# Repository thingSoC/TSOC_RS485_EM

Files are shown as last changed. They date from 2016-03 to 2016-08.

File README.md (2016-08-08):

# TSOC_RS485_EM
**TSOC_RS485_EM** is a ATMEGA328 based board with integrated RS485 driver, an Embedded Module for thingSoC.

The **TSOC_RS485_EM** connects any thingSoC or Mikrobus module to an RS485 compatible slave interface,
including a variety of analog sensors, such as Temperature, Wind, Pressure, Air Quality, and much more.
The **TSOC_RS485_EM** can be configured as either a thingSoC master module (female connectors), or a thingSoC slave module (male connectors),
which is implemented as an assembly/build time option.
 
---------------------------------------

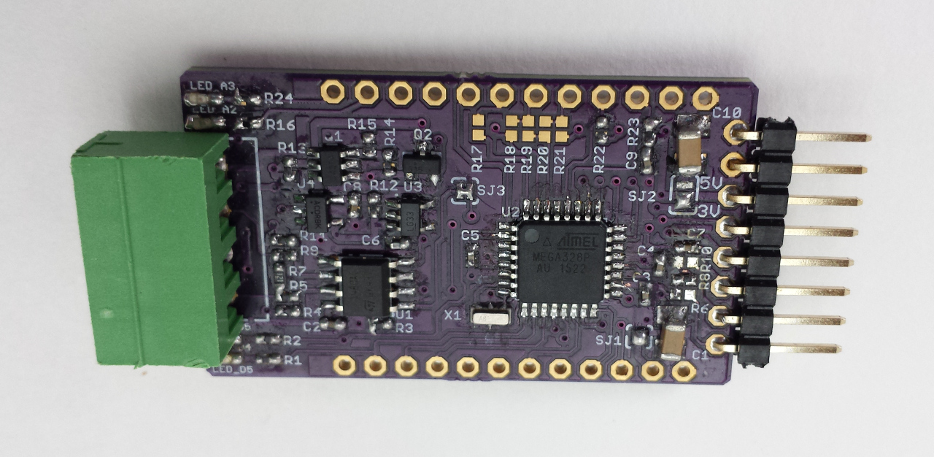
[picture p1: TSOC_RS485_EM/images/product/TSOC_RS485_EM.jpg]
thingSoC TSOC_NEOLED
[TSOC_RS485_EM](https://github.com/thingSoC/TSOC_RS485_EM/)

* [thingSoC Compliant Module](http://www.thingsoc.com)
* [Mikrobus Compatible Module](http://www.mikroe.com/mikrobus/) 
* [Modbus](http://www.modbus.org/specs.php) Compliant Slave Interface
* [5 Volt](https://en.wikipedia.org/wiki/Modbus) Nominal Power Input with ESD and OV/OC protections
* Supports Analog  Inputs  (ADC) 
* Supports Digital Outputs (GPIO)
* Supports Digital Inputs  (GPIO)
* Supports Remote I2C Interface
* Supports Remote UART Interface
* Supports Remote SPI Interface

## Protocols

* DMX512, RDM512
* Modbus
* Vending Machine Bus

---------------------------------------
## Example Applications

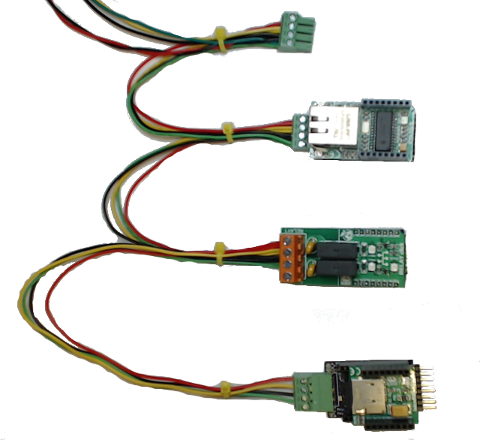
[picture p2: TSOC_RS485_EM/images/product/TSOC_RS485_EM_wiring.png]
thingSoC TSOC_NEOLED
[TSOC_RS485_EM Example Wiring](https://github.com/thingSoC/TSOC_RS485_EM/)

* [Modbus Weather Sensor](http://www.mikroe.com/click/weather/) BOSCH BME280 Temp, Humidity, Air Pressure
* [Modbus Methane Sensor](http://www.mikroe.com/click/methane/) MQ-4 Sensor for Methane (CH4) 
* [Modbus Air Quality Sensor](http://www.mikroe.com/click/air-quality/) MQ-135 Sensor for Harmful Gasses
* [Modbus Lightning Sensor](http://www.mikroe.com/click/thunder/) AS3935 Lighting Strike Detector
* [Modbus Controlled Relay](http://www.mikroe.com/click/relay/) G6D1AASI Power Relay Control Module

---------------------------------------
## 3D Model (Sketchup)

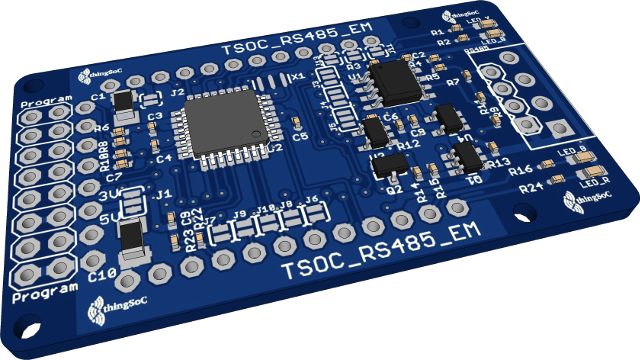
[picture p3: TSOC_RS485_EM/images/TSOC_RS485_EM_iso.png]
thingSoC TSOC_RS485_EM


---------------------------------------
## Project Status

* 02/18/2016 : Revision 4.0 Release for PCB fab
* 03/07/2016 : First Prototypes, board bringup is good
* 03/14/2016 : Revision 5.0 Released for PCB
* 04/06/2016 : Revision 6.0 Released for PCB

## Revision 6.0 Notes: ##

* Pinout Changes, D5/D8/D9 added as a second serial choice
* Disconnect jumpers added to all shared pins
* A7 used as AREF calibration input
* A6 used as VCC monitor input
* Both 3.5mm and 2.54mm connector patterns added

---------------------------------------

## Documentation Index <a name="documentation_index"/>

[TSOC_RS485_EM Quick Start Guide](https://github.com/thingSoC/TSOC_RS485_EM/blob/master/TSOC_RS485_EM/docs/QuickStart.md)

[TSOC_RS485_EM User Guide](https://github.com/thingSoC/TSOC_RS485_EM/blob/master/TSOC_RS485_EM/docs/UserGuide.md)

[TSOC_RS485_EM Theory of Operation](https://github.com/thingSoC/TSOC_RS485_EM/blob/master/TSOC_RS485_EM/docs/TheoryOfOperation.md)

[thingSoC Organization Website](http://thingSoC.github.io)

[thingSoC FAQ - Frequently Asked Questions](http://thingsoc.github.io/support/faq.html)

---------------------------------------

[  
*thingSoC*](http://thingsoc.github.io)

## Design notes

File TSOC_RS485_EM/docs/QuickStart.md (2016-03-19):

# TSOC_RS485_EM Quick Start Guide

Welcome! <br>
The **TSOC_RS485_EM**  Quick Start Guide is a series of quick steps to try out your new board.

---------------------------------------

## Quick Start Guide <a name="quickstartguide_index"/>

1. Plug a USB-UART (such as an FTDI cable) from your computer/tablet/etc. 
   or other USB power source to the **TSOC_RS485_EM**
2. Open the Arduino IDE
3. Select "Tools -> Board Manager -> Board -> Ardunio Pro or Mini"
4. Select "Tools -> Port -> COMX:", where X is your USB-UART
5. Select "File -> Examples -> Basics -> Blink"
6. Change "int LED=13;" to "int LED=5;" to blink the Yellow LED  
   Change "int LED=13;" to "int LED=4;" to blink the Blue LED  
   Change "int LED=13;" to "int LED=A2;" to blink the Green LED  
   Change "int LED=13;" to "int LED=A3;" to blink the Red LED  
7. Select "Sketch -> Upload" to load your sketch into the **TSOC_RS485_EM**
8. Observe the LED Blinking

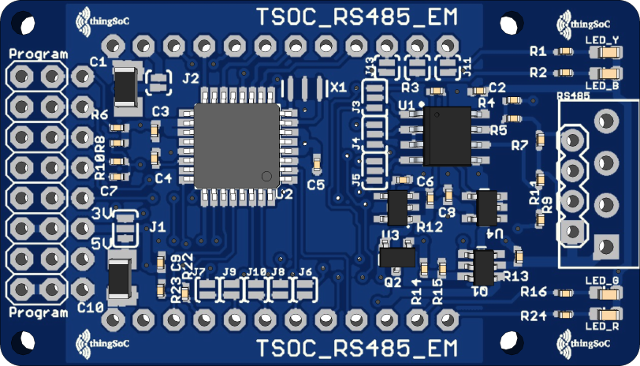
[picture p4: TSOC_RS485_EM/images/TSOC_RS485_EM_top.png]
thingSoC TSOC_RS485_EM
[  
*TSOC_RS485_EM*](https://github.com/thingSoC/TSOC_RS485_EM/)

---------------------------------------

## Documentation Index <a name="documentation_index"/>

[TSOC_RS485_EM Quick Start Guide](https://github.com/thingSoC/TSOC_RS485_EM/blob/master/TSOC_RS485_EM/docs/QuickStart.md)

[TSOC_RS485_EM User Guide](https://github.com/thingSoC/TSOC_RS485_EM/blob/master/TSOC_RS485_EM/docs/UserGuide.md)

[TSOC_RS485_EM Theory of Operation](https://github.com/thingSoC/TSOC_RS485_EM/blob/master/TSOC_RS485_EM/docs/TheoryOfOperation.md)

[thingSoC Organization Website](http://thingSoC.github.io)

[thingSoC FAQ - Frequently Asked Questions](http://thingsoc.github.io/support/faq.html)

---------------------------------------

[  
*thingSoC*](http://thingsoc.github.io)

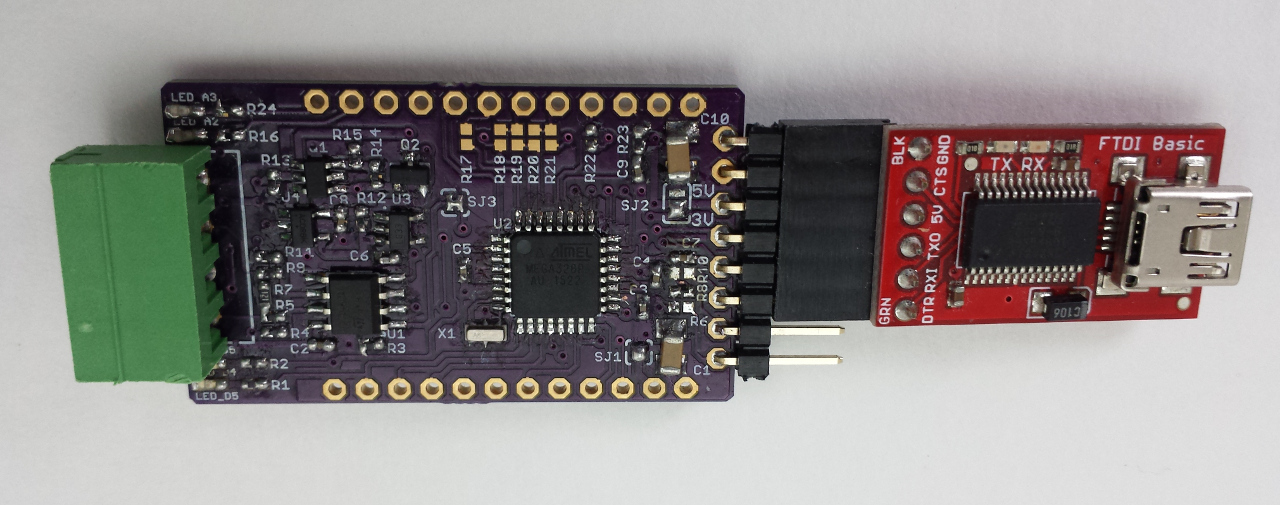
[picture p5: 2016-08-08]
TSOC_RS485_EM/images/product/TSOC_RS485_EM_prog_FTDI.jpg

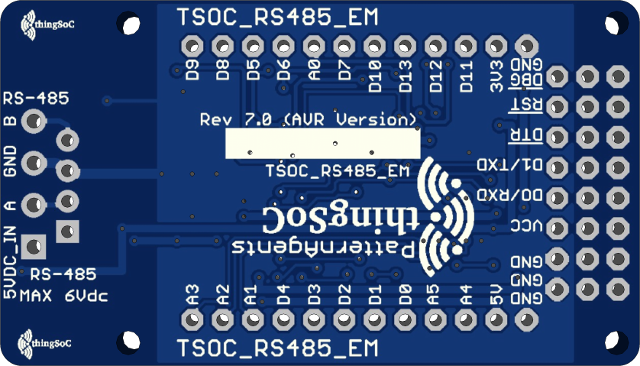
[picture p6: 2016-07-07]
TSOC_RS485_EM/images/TSOC_RS485_EM_bot.png

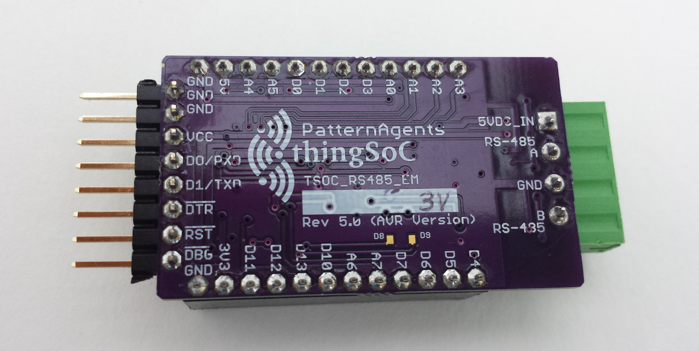
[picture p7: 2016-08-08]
TSOC_RS485_EM/images/product/TSOC_RS485_EM_bot.png

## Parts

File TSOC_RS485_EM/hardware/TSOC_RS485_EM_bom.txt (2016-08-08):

Partlist exported from U:/PatternAgents/eagle/TSOC_Modules/TSOC_RS485_EM/TSOC_RS485_EM/TSOC_RS485_EM.sch at 7/7/2016 11:09:10 AM

Qty Value                  Device                 Package               Parts                      Description                                            
5                          JMP-2-NO               JMP-2-NO              J6, J7, J8, J9, J10        Two Terminal Jumper - Normally Open                    
4                          LED0603                LED-0603              LED_B, LED_G, LED_R, LED_Y LEDs                                                   
1                          M04PTH                 1X04                  JP1                        Header 4                                               
1                          M04SCREW               SCREWTERMINAL-3.5MM-4 RS485                      Header 4                                               
1                          M08X2                  2X8                   J14                        .1" headers, two rows of 8 each                        
7   0.1uF                  CAPTYP                 EIA-0402              C2, C3, C4, C5, C7, C8, C9 Capacitor                                              
1   100                    RESISTOR0402-MIN       EIA-0402-MIN          R13                        Resistor                                               
3   10K                    RESISTOR0402-MIN       EIA-0402-MIN          R3, R8, R12                Resistor                                               
1   120                    RESISTOR0402-MIN       EIA-0402-MIN          R7                         Resistor                                               
4   1K                     RESISTOR0402-MIN       EIA-0402-MIN          R1, R2, R16, R24           Resistor                                               
2   22uF                   CPOL-EUSMCB            SMC_B                 C1, C10                    POLARIZED CAPACITOR, European symbol                   
1   470pF                  CAPTYP                 EIA-0402              C6                         Capacitor                                              
5   4K7                    RESISTOR0402-MIN       EIA-0402-MIN          R4, R11, R14, R22, R23     Resistor                                               
2   56                     RESISTOR0402-MIN       EIA-0402-MIN          R5, R9                     Resistor                                               
1   6K8                    RESISTOR0402-MIN       EIA-0402-MIN          R15                        Resistor                                               
1   8MHZ                   RESONATOR8MHZ          RESONATOR-SMD         X1                         Resonator                                              
1   ATMEGA328              ATMEGA168              TQFP32-08             U2                                                                                
2   DNP                    RESISTOR0402-MIN       EIA-0402-MIN          R6, R10                    Resistor                                               
1   FDC6420C               FDC6420C               SOT95P280X110-6N      Q1                         N and P Channel Power Trench MOSFETs                   
4   JMP-2-NC               JMP-2-NC               JMP-2-NC              J2, J11, J12, J13          Two Terminal Jumper - Normally Closed                  
4   JMP-3-1_2              JMP-3-1_2              JMP-3-1_2             J1, J3, J4, J5             Three Terminal Jumper - 1 & 2 Connected                
1   MIC5219 3.3V           V_REG_MIC52193.3V      SOT23-5               U3                         V_REG MIC5219                                          
1   MOSFET-NCHANNELAO3404A MOSFET-NCHANNELAO3404A SOT23-3               Q2                         Common NMOSFET Parts                                   
1   NCP361SNT1G            NCP361SNT1G            SOP95P275X110-5N      U4                         USB Positive Overvoltage Protection Controller (subs. MIC2005A-1YM5/MIC2019YM6)       
1   ST1480ACSOIC           ST1480ACSOIC           SO08                  U1                         ST Microelectronics ST1480AC RS-485/RS-422 Transceiver 
1   TSOC-32-BB             TSOC-32-BB             TSOC-BB-S32           TSOC                       thingSoC Thirty-Two (32) Pin Socket                    
4   TSOC-LOGO-SMALL        TSOC-LOGO-SMALL        TSOC-LOGO-SML         U$5, U$6, U$7, U$8         thingSoC Logo                                          
1   TSOC-PCB-PLUS          TSOC-PCB-PLUS          TSOC-BB-BRD-PLUS      U$3                        thingSoC PCB Outlines

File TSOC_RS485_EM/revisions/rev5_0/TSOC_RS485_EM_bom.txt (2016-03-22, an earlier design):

Partlist exported from /home/moxon/github/TSOC_RS485_EM/TSOC_RS485_EM/revisions/TSOC_RS485_EM_R5_0.sch at 3/14/16 5:49 PM

Qty Value                  Device                 Package               Parts                            Description                                            
1   Red                    LED0603                LED-0603              LED_A2                           Red
1   Green                  LED0603                LED-0603              LED_A3                           Greeen
1   Blue                   LED0603                LED-0603              LED_D4                           Blue
1   Yellow                 LED0603                LED-0603              LED_D5                           Yellow                                                   
1   SCREWTERMINAL          TE 1776275-4           3.5MM-4               RS485                            Header 4 Pin Screw Terminal                                                                                     
7   0.1uF                  CAP0402-CAP            0402-CAP              C2, C3, C4, C5, C7, C8, C9       Capacitor                                              
3   10K                    RESISTOR0402           0402-RES              R3, R8, R12                      Resistor                                               
1   120                    RESISTOR0402           0402-RES              R7                               Resistor                                               
4   1K                     RESISTOR0402           0402-RES              R1, R2, R16, R24                 Resistor                                               
2   22uF                   1206                   SMC_B                 C1, C10                          Capacitor                   
1   470pF                  CAP0402-CAP            0402-CAP              C6                               Capacitor                                              
5   4K7                    RESISTOR0402           0402-RES              R4, R11, R14, R22, R23           Resistor                                               
3   56                     RESISTOR0402           0402-RES              R5, R9, R13                      Resistor                                               
1   6K8                    RESISTOR0402           0402-RES              R15                              Resistor                                               
1   16MHZ                  CSTCE16M0V53-R0        RESONATOR-SMD         X1                               Resonator                                              
1   ATMEGA328P             ATMEGA328P             TQFP32-08             U2                               Atmel AVR (Arduino Compatible, Optiboot loaded)                                                       
1   FDC6420C               FDC6420C               SOT95P280X110-6N      Q1                               N and P Channel Power Trench MOSFETs                              
1   MIC5219 3.3V           V_REG_MIC52193.3V      SOT23-5               U3                               V_REG MIC5219                                          
1   MOSFET-NCHANNELAO3404A MOSFET-NCHANNELAO3404A SOT23-3               Q2                               Common NMOSFET Parts                                   
1   NCP361SNT1G            NCP361SNT1G            SOP95P275X110-5N      U4                               USB Positive Overvoltage Protection Controller         
1   ST1480ACSOIC           ST1480ACSOIC           SO08                  U1                               ST Microelectronics ST1480AC RS-485/RS-422 Transceiver 
1   TSOC-8-SERPROG         TSOC-8-SERPROG         TSOC-8-SERPROG        SERPROG                          thingSoC eight (8) Pin programming header                                  
7   DNP                    RESISTOR0402           0402-RES              R6, R10, R17, R18, R19, R20, R21 Resistor (Do Not Pupulate for Default Version)

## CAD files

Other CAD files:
TSOC_RS485_EM/eagleUp/TSOC_RS485_EM.skp

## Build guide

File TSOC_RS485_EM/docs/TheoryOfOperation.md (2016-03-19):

# TSOC_RS485_EM Theory of Operation

**TSOC_RS485_EM** is a ATMEGA328 based board with integrated RS485 driver, an Embedded Module for thingSoC.

The **TSOC_RS485_EM** connects any thingSoC or Mikrobus module to an RS485 compatible slave interface,
including a variety of analog sensors, such as Temperature, Wind, Pressure, Air Quality, and much more.
The **TSOC_RS485_EM** can be configured as either a thingSoC master module (female connectors), or a thingSoC slave module (male connectors),
which is implemented as an assembly/build time option.

---------------------------------------

[thingSoC TSOC_RS485_EM  
*TSOC_RS485_EM*](https://github.com/thingSoC/TSOC_RS485_EM/)

* [thingSoC Compliant Module](http://www.thingsoc.com)
* [Mikrobus Compatible Module](http://www.mikroe.com/mikrobus/) 
* [Modbus](http://www.modbus.org/specs.php) Compliant Slave Interface
* [5 Volt](https://en.wikipedia.org/wiki/Modbus) Nominal Power Input with ESD and OV/OC protections
* Supports Six (6) Analog  Inputs  (ADC) 
* Supports Six (6) Digital Outputs (3.3V)
* Supports Six (2) Digital Inputs  (3.3V)
* Supports Remote I2C Interface
* Supports Remote UART Interface
* Supports Remote SPI Interface
* Easily add Modbus Interface support to any device or sensor, with little development time or experience

---------------------------------------

## Theory of Operation <a name="theory_index"/>

### Page A : ATMEGA328 Processor (Atmel AVR - Arduino Compatible)<a name="PAGEA"/>

The **TSOC_RS485_EM** can use either an ATMEGA328 or ATMEGA328P in a 32 PIN TQFP Package.

X1 is a Murata Resonator, typically populated with an 8MHz component (16 MHz by request).

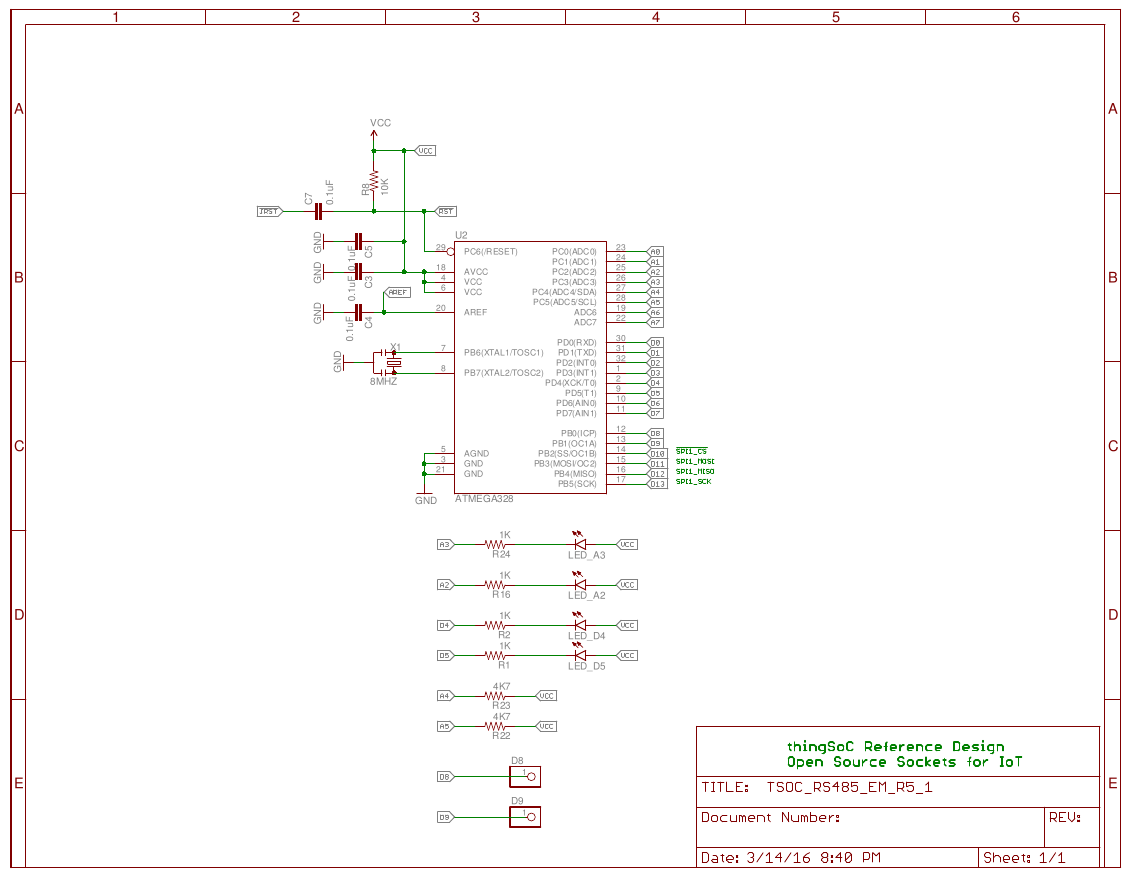
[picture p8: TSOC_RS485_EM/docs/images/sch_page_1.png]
Schematic Page A


### Page B : thingSoC Compliant Socket <a name="PAGEB"/>

The **TSOC_RS485_EM** incorporates a standard thingSoC Compliant socket pattern, and can be configured for either master or slave socket operation.

R17, R18, R19, R20, and R21 are used to swap transmit amnd receive, or to enable or disable external connections for D0, D1, and D2.
Normally D0, D1, and D2 are used for the RS-485 tranceiver, and so R17, R18, R19, R20, and R21 are DNP (Do Not Populate).

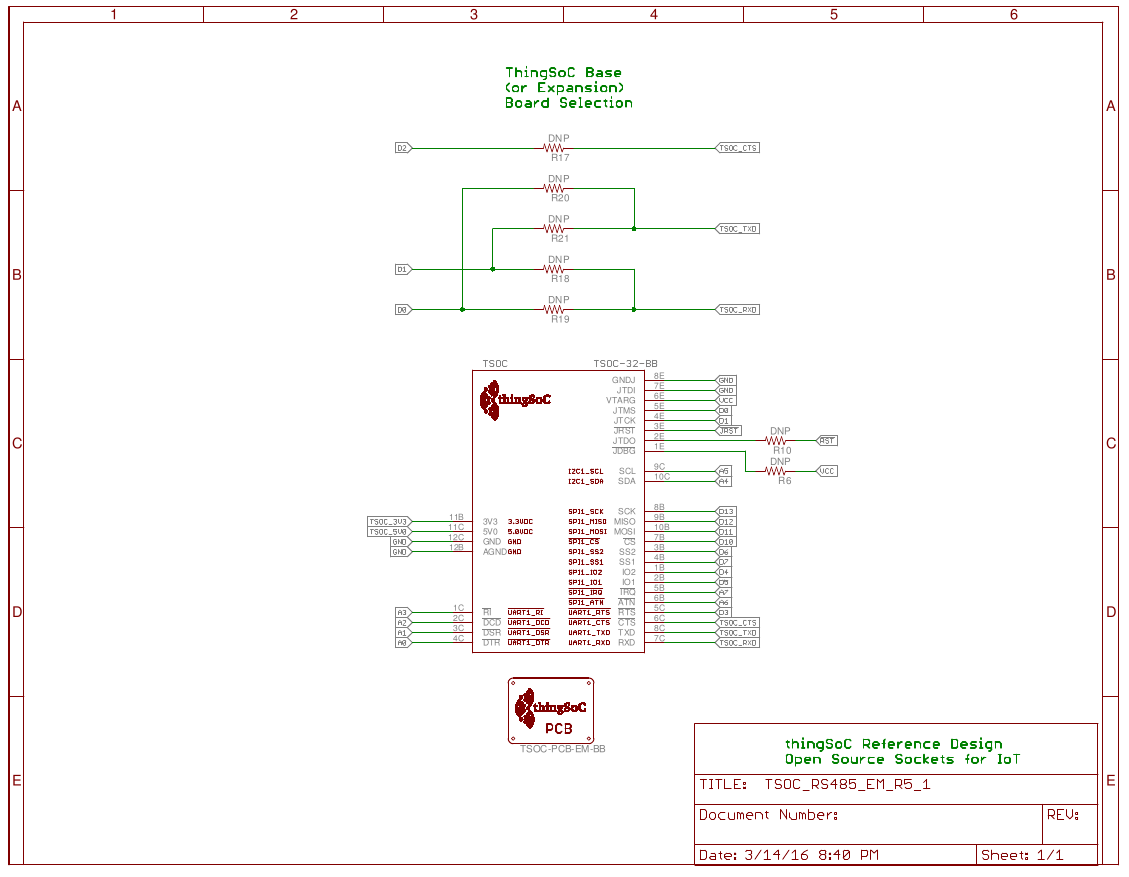
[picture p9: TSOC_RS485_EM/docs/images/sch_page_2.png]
Schematic Page B


### Page C : Power Supply <a name="PAGEC"/>

Q1, a [FDC6420C](https://www.fairchildsemi.com/datasheets/FD/FDC6420C.pdf) , is a complementary (N-Channel and P-Channel) power MOSFET 
used to select between the internal TSOC socket power (slave operation), and the external 5V power supply (master operation).
Resistor, R15 is used to "pull-down" the GATE of Q1P, turning it on, and enabling the TSOC socket 5V to apply power to U4 (VIN).
If external 5V0 is connected, then Resistor R13 powers the GATE of Q1N, turning it on (and turning Q1P off...),
enabling external 5V0 to apply power to U4 (VIN).

U4, a [NCP361](http://www.onsemi.com/pub_link/Collateral/NCP361-D.PDF) , is a USB VBUS protection device, with an error output flag to indicate
an undervoltage, overvoltage, or overcurrent condition. The !5V0_FAULT (error flag) signal is active low, 
and is used to disable U3, the 3.3 Volt regulator. U3 a [MIC5219](http://www.micrel.com/_PDF/mic5219.pdf) Low DropOut Regulator (LDO),
is used to provide the 3.3 Volt power rail. This type of active power protection scheme is much faster (5/1000 of a second), 
and much more efficient than chemical or resetable fuses, such as the PPTC fuse normally used for USB power on the typical Arduino board.

This type of active power protection scheme also protects your Li-Po battery from being completely discharged and ruined.
U4, the [NCP361](http://www.onsemi.com/pub_link/Collateral/NCP361-D.PDF) also includes a low-voltage (undervoltage) comparator,
and will keep the system from powering up if the battery has been discharged too much, preventing your battery from permanent damage. 

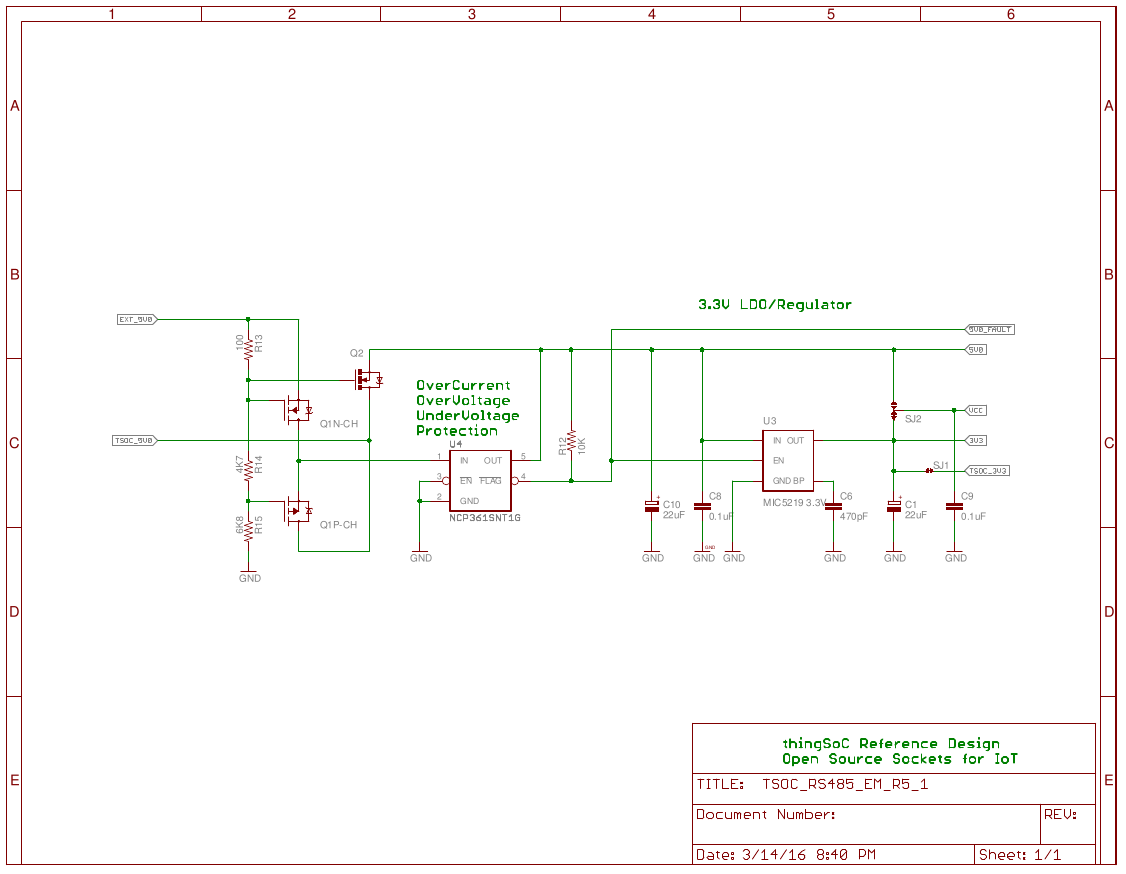
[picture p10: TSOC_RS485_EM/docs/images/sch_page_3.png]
Schematic Page C


### Page D : RS485 Tranceiver <a name="PAGED"/>

U1, an ST1480ACSOIC, is an RS-485 transceiver, capable of either 3.3V or 5V operation.

Solder Jumper, SJ3 is used to disconnect the onboard ST1480ACSOIC RS-485 transceiver,
and enables the use of an external driver for the main UART on D0 & D1.

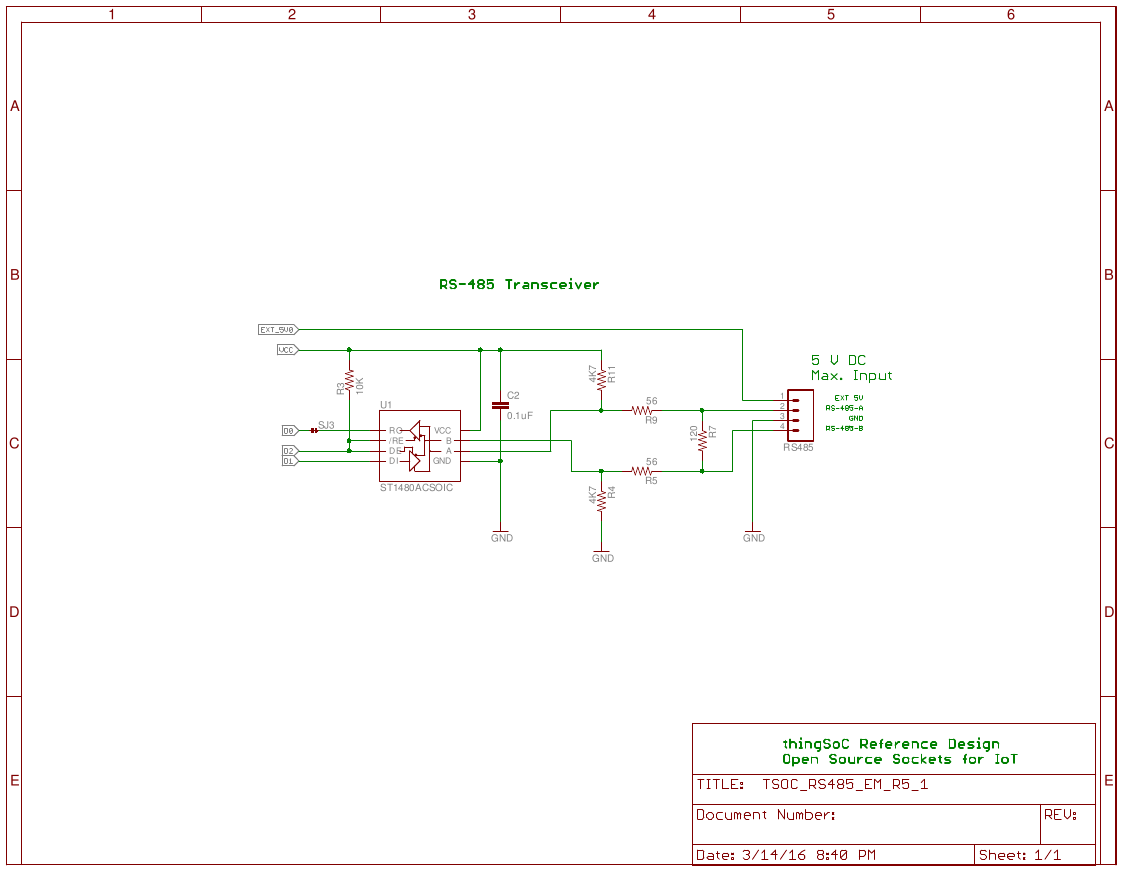
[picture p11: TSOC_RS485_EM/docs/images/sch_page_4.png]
Schematic Page D


---------------------------------------

Limitations: 

1) The **TSOC_RS485_EM** can use either 3.3V or 5V for VCC, either a 3.3V or 5V FTDI USB-UART can be used.

2) The **TSOC_RS485_EM** expects a 5.0V Volt external power supply input, do not exceed 5.0V power input (i.e. USB). 

---------------------------------------

## Jumper Settings <a name="jumpers"/>

* SJ1 - TSOC 3.3V Enable : Enables/Disables 3.3V power to an external thingSoC board. Default is enabled (connected).

* SJ2 - VCC 3,3V or 5.0V select, up for 5.0 Volt operation, down for 3.3 Volt operation. Default is 3.3V VCC (down).

* SJ3 - Internal RS-485 Driver Enable. Default is enabled (connected).

---------------------------------------

## Master/Slave Settings <a name="master_slave"/>

* MASTER - Using Onboard RS-485 Tranceiver, configure as follows:  
  SJ1 : Installed  
  SJ3 : Installed  
  R17, R18, R19, R20, R21 : Removed (not populated)  
  
* MASTER - disable Onboard RS-485 Tranceiver, configure as follows:  
  SJ1 : Installed  
  SJ3 : Removed  
  R17, R19, R21 : Installed (1K Ohms)  
  R18, R20 : Removed (not populated)  
  
* SLAVE - Using Onboard RS-485 Tranceiver, configure as follows:  
  SJ1 : Removed  
  SJ3 : Installed  
  R17, R18, R19, R20, R21 : Removed (not populated)  
  
* SLAVE - disable Onboard RS-485 Tranceiver, configure as follows:  
  SJ1 : Removed  
  SJ3 : Removed  
  R17, R18, R20 : Installed (1K Ohms)  
  R19, R21 : Removed (not populated)  

---------------------------------------

## Documentation Index <a name="documentation_index"/>

[TSOC_RS485_EM Quick Start Guide](https://github.com/thingSoC/TSOC_RS485_EM/blob/master/TSOC_RS485_EM/docs/QuickStart.md)

[TSOC_RS485_EM User Guide](https://github.com/thingSoC/TSOC_RS485_EM/blob/master/TSOC_RS485_EM/docs/UserGuide.md)

[TSOC_RS485_EM Theory of Operation](https://github.com/thingSoC/TSOC_RS485_EM/blob/master/TSOC_RS485_EM/docs/TheoryOfOperation.md)

[thingSoC Organization Website](http://thingSoC.github.io)

[thingSoC FAQ - Frequently Asked Questions](http://thingsoc.github.io/support/faq.html)

---------------------------------------

[  
*thingSoC*](http://thingsoc.github.io)

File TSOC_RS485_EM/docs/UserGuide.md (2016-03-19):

# TSOC_RS485_EM User Guide

**TSOC_RS485_EM** is a ATMEGA328 based board with integrated RS485 driver, an Embedded Module for thingSoC.

The **TSOC_RS485_EM** connects any thingSoC or Mikrobus module to an RS485 compatible slave interface,
including a variety of analog sensors, such as Temperature, Wind, Pressure, Air Quality, and much more.
The **TSOC_RS485_EM** can be configured as either a thingSoC master module (female connectors), or a thingSoC slave module (male connectors),
which is implemented as an assembly/build time option.

---------------------------------------

## User Guide <a name="userguide_index"/>

[thingSoC TSOC_RS485_EM  
*TSOC_RS485_EM*](https://github.com/thingSoC/TSOC_RS485_EM/)

## Overview

The **TSOC_RS485_EM** is software/firmware compatible with a standard Arduino-Pro model,
employing the same ATMEL ATMEGA328 Microcontroller and the OptiBoot bootloader.
While any AVR development tools (i.e. Atmel Studio, etc.) may be used with the **TSOC_RS485_EM**,
this guide is primarily intended for use with the [Arduino IDE](https://www.arduino.cc/en/Main/Software) from [Arduino.cc](https://www.arduino.cc/).
The included files in the "examples" directory, are Arduino programs, known as "sketches", and using the .ino filename suffix.

## Why RS-485?

[RS-485](https://en.wikipedia.org/wiki/RS-485) is an older TIA/EIA standard for balanced digital multipoint, or "multi-drop" systems.
Examples of [RS-485](https://en.wikipedia.org/wiki/RS-485) based systems include theatre lighting (DMX/RDM512), 
early networking (Apple Talk), industrial process control (Modbus), vending machine bus control (VMB), and many other protocols and applications. 
The **TSOC_RS485_EM** is a simple and flexbile bridge tool for connecting a variety of other devices (sensors, relays, lights),
as well as other communications protocols (Ethernet, Wi-Fi, Bluetooth, etc) using [RS-485](https://en.wikipedia.org/wiki/RS-485).

## Why thingSoC?

[thingSoC](http://thingSoC.github.io) is an open source standard that defines a vendor independent socket system 
for the creation of new Internet Things; it addresses many of the limitations of current product offerings and standards, 
by adding capabilities such as automatic device discovery, device configuration, monitoring, instrumentation, and testing.

## TSOC_RS485_EM Compliance & Compatibility

The **TSOC_RS485_EM** is a [thingSoC](http://thingSoC.github.io) Compliant Module, and implements the [thingSoC Standard Embedded Module Format](http://thingSoC.github.io),
which defines the physical size, connector locations, mounting hole locations, as well as the automatic device discovery, device configuration, monitoring, instrumentation, 
and testing protocols. 

The **TSOC_RS485_EM** is also [MikroBus](http://www.mikroe.com/mikrobus/) compatible in most situations (depending on the pinout of the specific Mikrobus Module), 
and can use the majority of [Click](http://www.mikroe.com/click/) modules, available from [MikroElectronika](http://www.mikroe.com/). 
[MikroBus](http://www.mikroe.com/mikrobus/) and [Click](http://www.mikroe.com/click/) are registered tradmarks of [MikroElectronika](http://www.mikroe.com/).
We're busy doing interoperability testing using a variety of the [Click](http://www.mikroe.com/click/) modules with [thingSoC](http://thingSoC.github.io) modules,
and will be adding those as examples, as they are tested and verified. The [MikroElectronika](http://www.mikroe.com/) [Click](http://www.mikroe.com/click/) modules are inexpensive, 
and available from a number of [distributors](http://www.mikroe.com/distributors/) worldwide, and they are a good compliment to the unique features available
with [thingSoC](http://thingSoC.github.io) modules; however unlike [thingSoC](http://thingSoC.github.io) modules, the [Click](http://www.mikroe.com/click/) modules
do not include the automatic device discovery, device configuration, monitoring, instrumentation, features available with [thingSoC](http://thingSoC.github.io) modules.

## Examples

From the Arduino IDE, select File -> Examples -> TSOC_RS485_EM -> (example)

1) Blinky       :  Blinks the onboard Red, Green, Blue, and Yellow LEDs in sequence

2) DMX Master   :  Transmits a "fade-up" in brightness on DMX Channels 12 - 17

3) DMX Slave    :  Receive commands on DMX Channels 12-17  
  (12=Red, 13=Green, 14=Blue 15=Yellow, 16=Relay1, 17=Relay2)

4) Modbus Slave :  Receive commands on Modbus Address 1  
  (Holding Registers map to EEPROM, Coils to GPIO/Relays, etc.)

---------------------------------------

## Documentation Index <a name="documentation_index"/>

[TSOC_RS485_EM Quick Start Guide](https://github.com/thingSoC/TSOC_RS485_EM/blob/master/TSOC_RS485_EM/docs/QuickStart.md)

[TSOC_RS485_EM User Guide](https://github.com/thingSoC/TSOC_RS485_EM/blob/master/TSOC_RS485_EM/docs/UserGuide.md)

[TSOC_RS485_EM Theory of Operation](https://github.com/thingSoC/TSOC_RS485_EM/blob/master/TSOC_RS485_EM/docs/TheoryOfOperation.md)

[thingSoC Organization Website](http://thingSoC.github.io)

[thingSoC FAQ - Frequently Asked Questions](http://thingsoc.github.io/support/faq.html)

---------------------------------------

[  
*thingSoC*](http://thingsoc.github.io)

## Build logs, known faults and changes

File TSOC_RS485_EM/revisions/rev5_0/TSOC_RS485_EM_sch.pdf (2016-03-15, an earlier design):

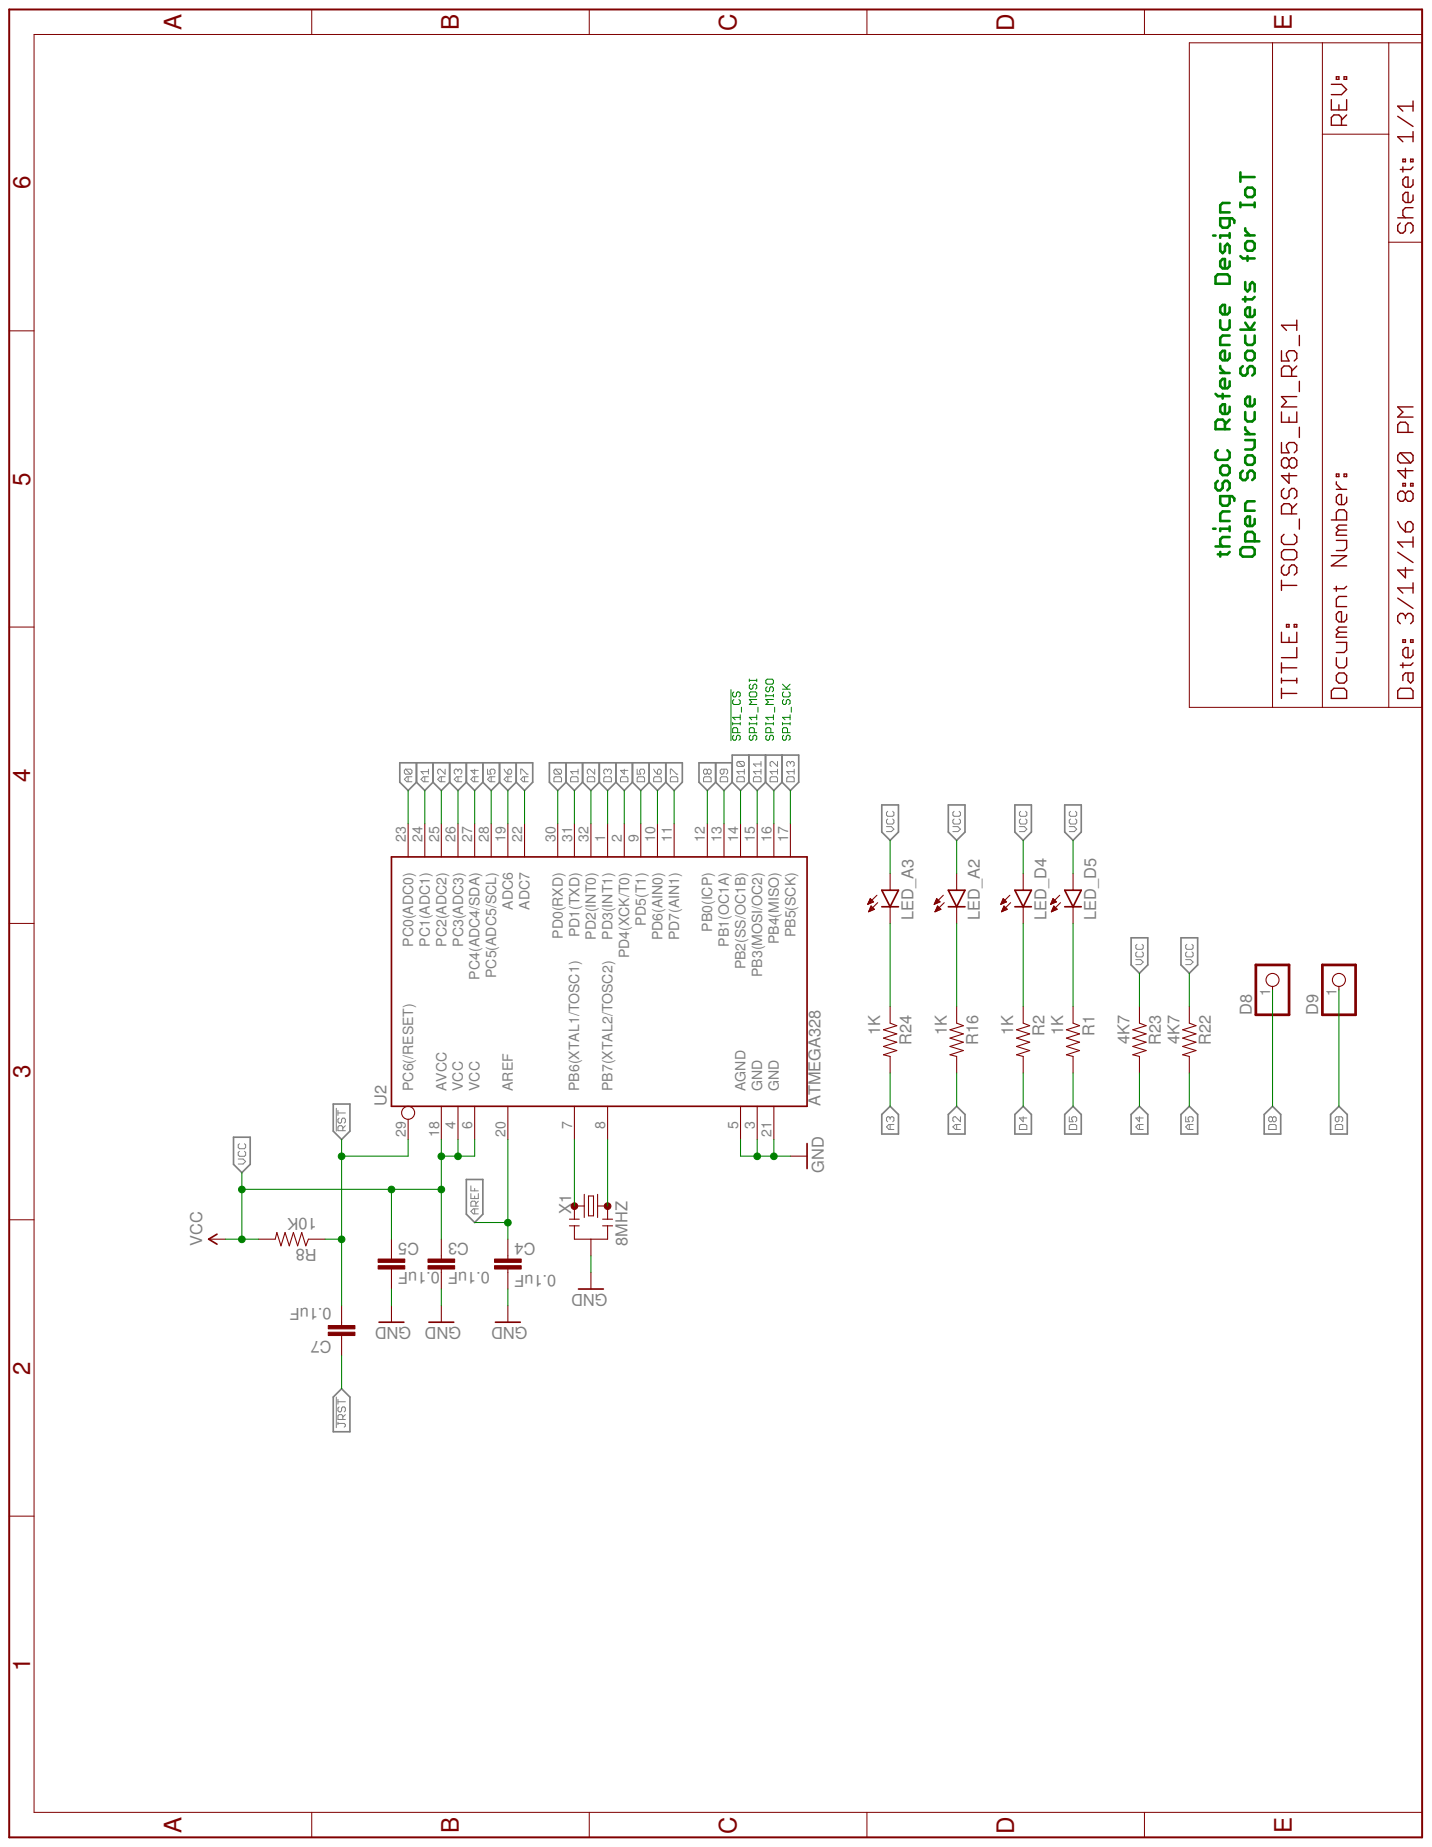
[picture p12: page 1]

PB4(MISO) 16 PB3(MOSI/OC2) 15 PB2(SS/OC1B) 14 PB1(OC1A) 13 PB0(ICP) 12 PD7(AIN1) 11 PD6(AIN0) 10 PD5(T1) 9 PD4(XCK/T0) 2 PD3(INT1) 1 PD2(INT0) 32 PD1(TXD) 31 PD0(RXD) 30 ADC7

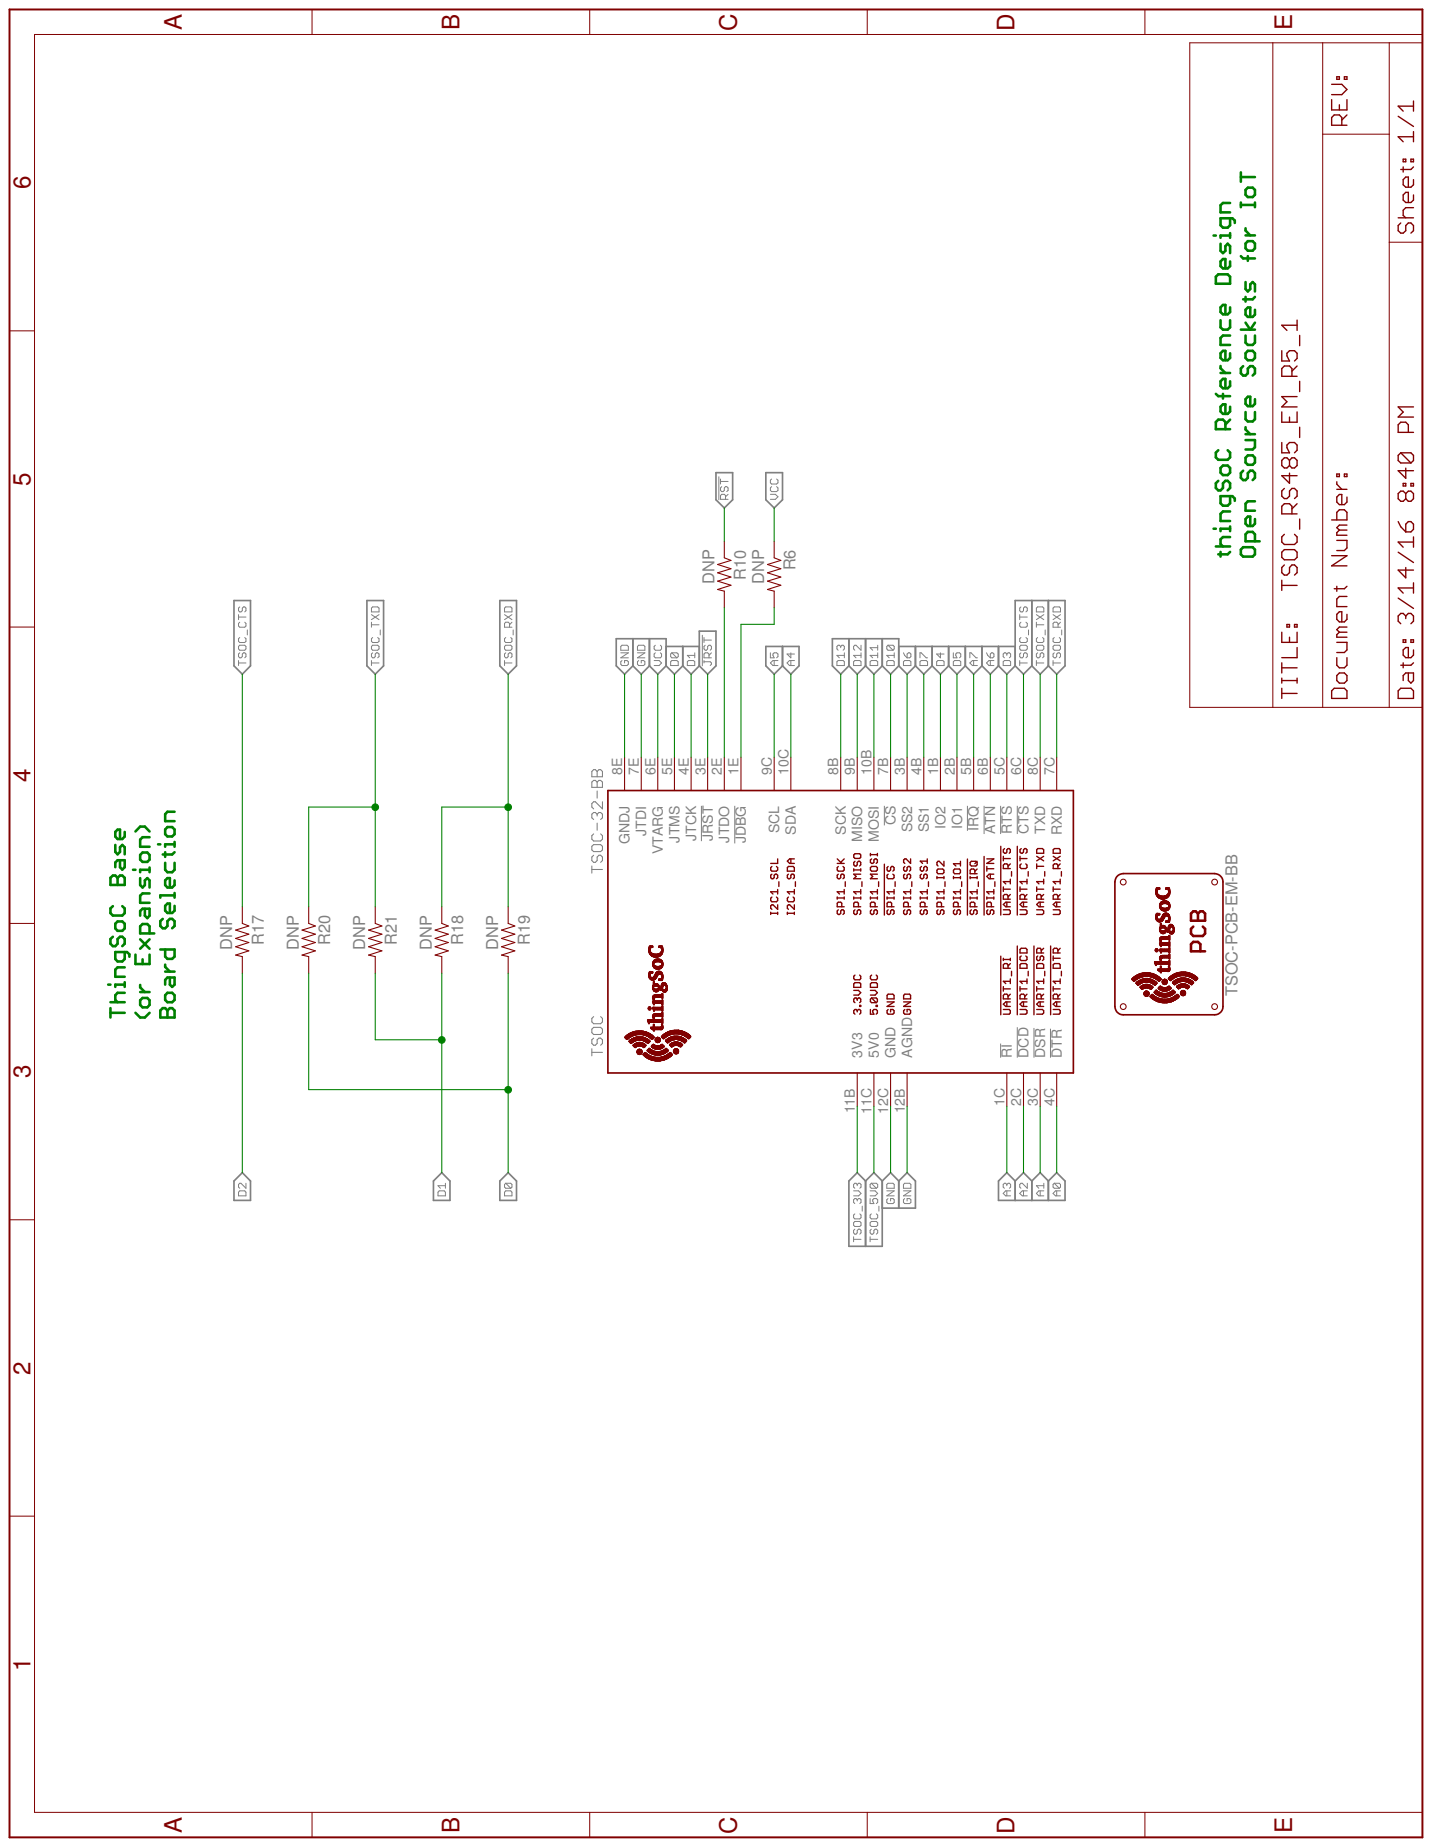
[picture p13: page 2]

TSOC-PCB-EM-BB

DNP DNP

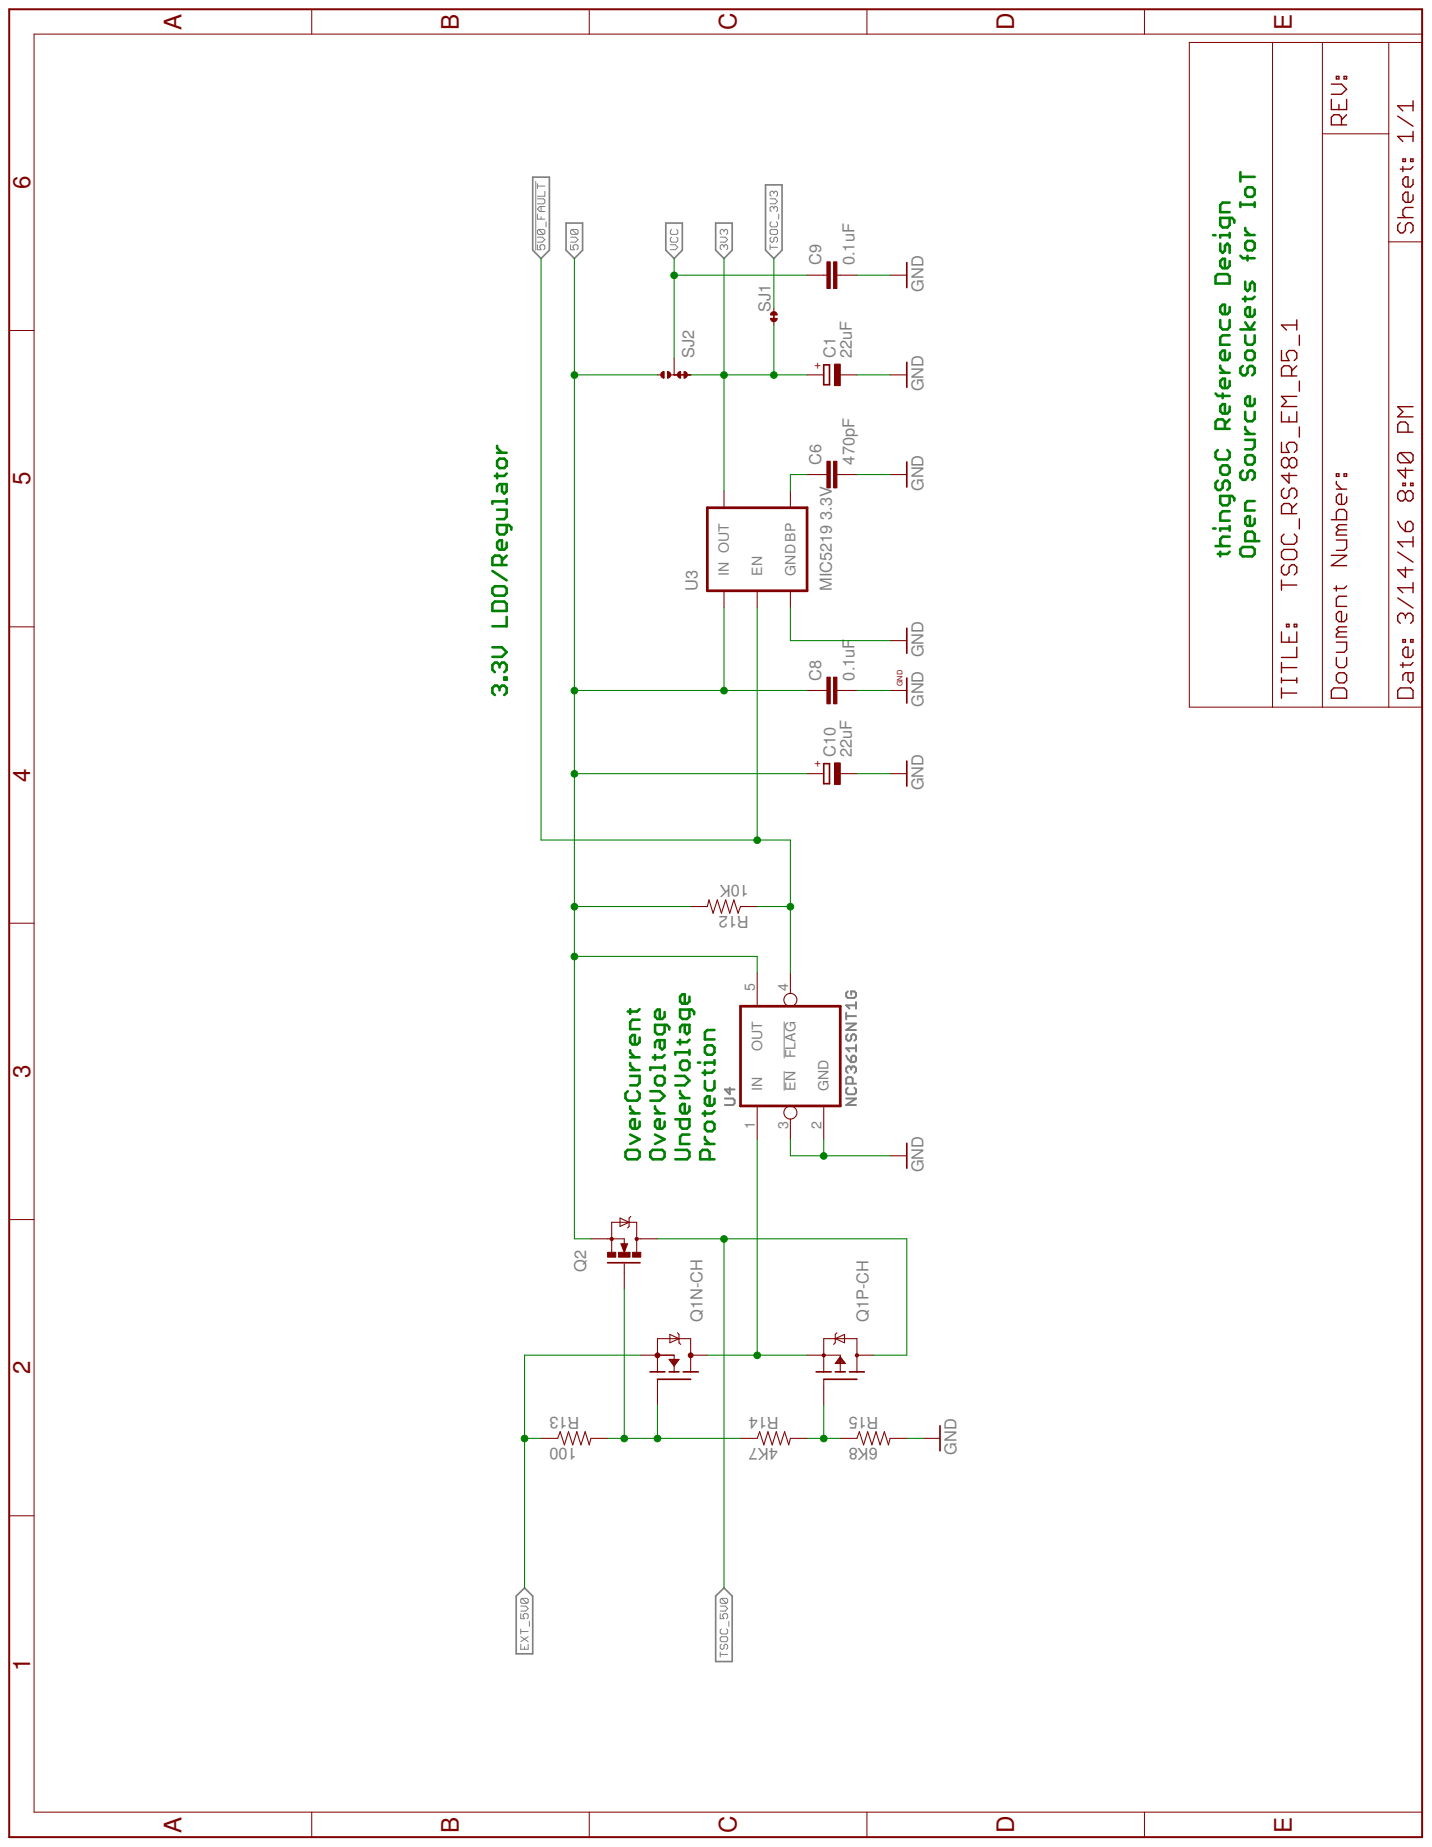
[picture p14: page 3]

0.1uF GND 1K TSOC-PCB-EM-BB 1K1K ST1480ACSOIC Fu1. 0 DNG Fu1. 0 DNG 8MHZ DNG ATMEGA328 GND K01 Fu1. 0 VCC 4K7 4K71K MIC5219 3.3VGND GND 470pF 0.1uF GND GND K01 001 7K4 8K6 GND 22uF 22uF GND GND DNP DNP DNP DNP 0.1uF GND DNP GND 5656 7K4 7K4 GND 021 DNP K01 Fu1. 0 DNG DNP C2 RS485 1234 ATN 6B RI 1C DCD 2C DSR 3C DTR 4C TXD 8C IO2 1B IO1 2B RTS 5C CTS 6C IRQ 5B SS2 3B SS1 4B CS 7B MOSI 10B MISO 9B SCK 8B GND 12C AGND 12B 3V3 11B RXD 7C SDA 10C SCL 9C 5V0 11C JDBG 1E JTDO 2E JRST 3E JTCK 4E JTMS 5E VTARG 6E JTDI 7E GNDJ 8E R24 R16 R1 U1RO/RE DEDI VCCBA GND 3 C 4 C X1 PB5(SCK) 17 PB7(XTAL2/TOSC2) 8 PB6(XTAL1/TOSC1) 7 GND 3 GND 21 VCC 4 VCC 6 AGND 5 AREF 20 AVCC 18 PB4(MISO) 16 PB3(MOSI/OC2) 15 PB2(SS/OC1B) 14 PB1(OC1A) 13 PB0(ICP) 12 PD7(AIN1) 11 PD6(AIN0) 10 PD5(T1) 9 PD4(XCK/T0) 2 PD3(INT1) 1 PD2(INT0) 32 PD1(TXD) 31 PD0(RXD) 30 ADC7 22 ADC6 19 PC5(ADC5/SCL) 28 PC4(ADC4/SDA) 27 PC3(ADC3) 26 PC2(ADC2) 25 PC1(ADC1) 24 PC0(ADC0) 23 PC6(/RESET) 29 U2 8 R7 C R22 R23 LED_D5 LED_A3 LED_A2 R2 LED_D4 U3INGNOD UT EN BP C6 C8 IN 1 EN 3 FLAG 4 GND 2 OUT 5 21 R Q1N-CH Q1P-CH 31 R 41 R 51 R C10 C1 R19 R18 R21 R20 SJ2 Q2 SJ1 C9 R10 R9 R5 11 R 4 R 7 R R6 3 R 5 C R17 D81 D91 SJ3 ABCDE ABCDE 1 2 3 4 5 6 ABCDE ABCDE 1 2 3 4 5 6 ABCDE ABCDE 1 2 3 4 5 6 ABCDE ABCDE 1 2 3 4 5 6 GND ++

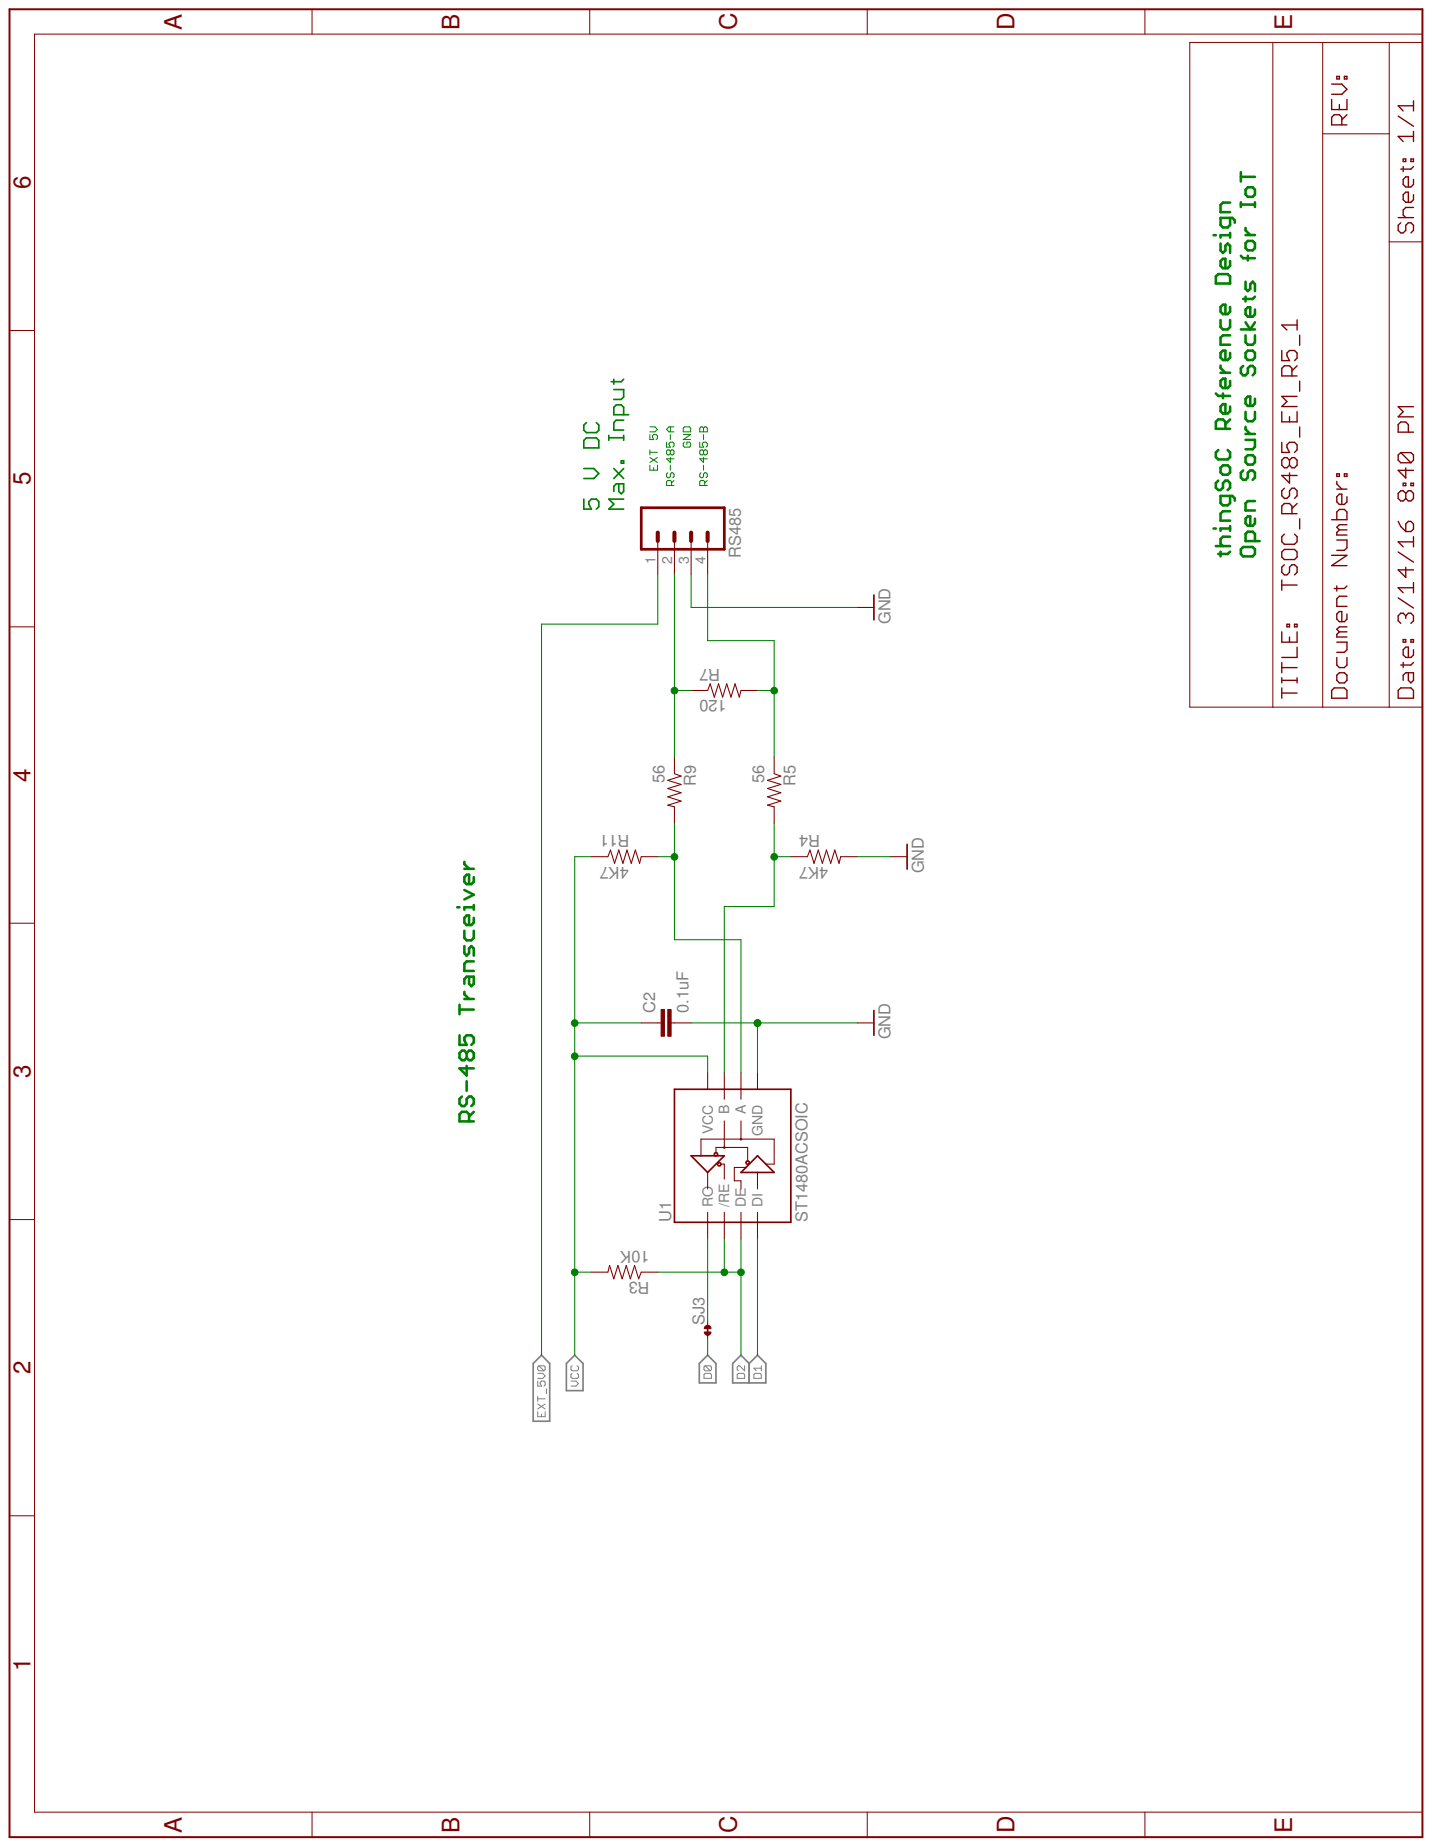
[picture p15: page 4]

0.1uF GND 1K TSOC-PCB-EM-BB 1K1K ST1480ACSOIC Fu1. 0 DNG Fu1. 0 DNG 8MHZ DNG ATMEGA328 GND K01 Fu1. 0 VCC 4K7 4K71K MIC5219 3.3VGND GND 470pF 0.1uF GND GND K01 001 7K4 8K6 GND 22uF 22uF GND GND DNP DNP DNP DNP 0.1uF GND DNP GND 5656 7K4 7K4 GND 021 DNP K01 Fu1. 0 DNG DNP C2 RS485 1234 ATN 6B RI 1C DCD 2C DSR 3C DTR 4C TXD 8C IO2 1B IO1 2B RTS 5C CTS 6C IRQ 5B SS2 3B SS1 4B CS 7B MOSI 10B MISO 9B SCK 8B GND 12C AGND 12B 3V3 11B RXD 7C SDA 10C SCL 9C 5V0 11C JDBG 1E JTDO 2E JRST 3E JTCK 4E JTMS 5E VTARG 6E JTDI 7E GNDJ 8E R24 R16 R1 U1RO/RE DEDI VCCBA GND 3 C 4 C X1 PB5(SCK) 17 PB7(XTAL2/TOSC2) 8 PB6(XTAL1/TOSC1) 7 GND 3 GND 21 VCC 4 VCC 6 AGND 5 AREF 20 AVCC 18 PB4(MISO) 16 PB3(MOSI/OC2) 15 PB2(SS/OC1B) 14 PB1(OC1A) 13 PB0(ICP) 12 PD7(AIN1) 11 PD6(AIN0) 10 PD5(T1) 9 PD4(XCK/T0) 2 PD3(INT1) 1 PD2(INT0) 32 PD1(TXD) 31 PD0(RXD) 30 ADC7 22 ADC6 19 PC5(ADC5/SCL) 28 PC4(ADC4/SDA) 27 PC3(ADC3) 26 PC2(ADC2) 25 PC1(ADC1) 24 PC0(ADC0) 23 PC6(/RESET) 29 U2 8 R7 C R22 R23 LED_D5 LED_A3 LED_A2 R2 LED_D4 U3INGNOD UT EN BP C6 C8 IN 1 EN 3 FLAG 4 GND 2 OUT 5 21 R Q1N-CH Q1P-CH 31 R 41 R 51 R C10 C1 R19 R18 R21 R20 SJ2 Q2 SJ1 C9 R10 R9 R5 11 R 4 R 7 R R6 3 R 5 C R17 D81 D91 SJ3 ABCDE ABCDE 1 2 3 4 5 6 ABCDE ABCDE 1 2 3 4 5 6 ABCDE ABCDE 1 2 3 4 5 6 ABCDE ABCDE 1 2 3 4 5 6 GND ++

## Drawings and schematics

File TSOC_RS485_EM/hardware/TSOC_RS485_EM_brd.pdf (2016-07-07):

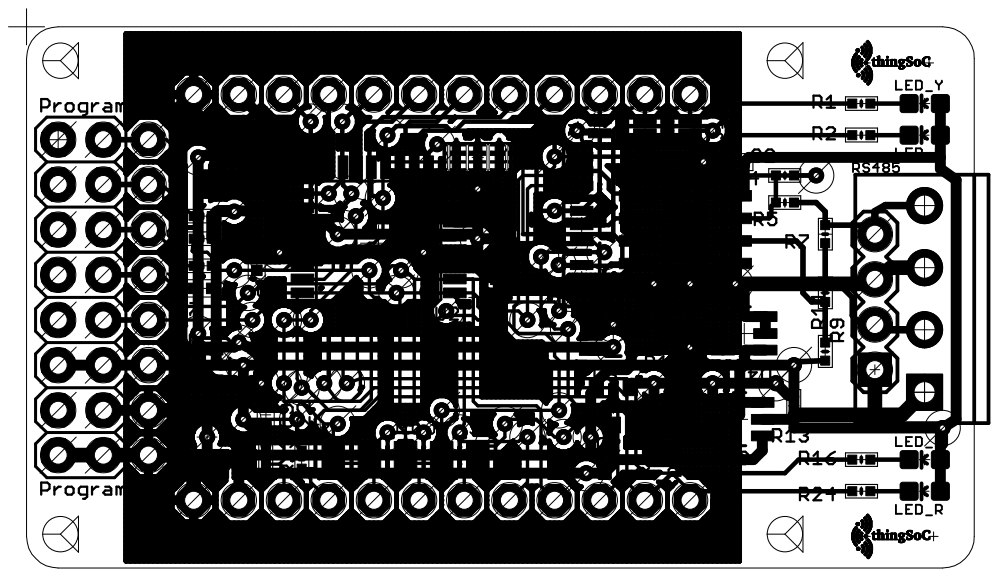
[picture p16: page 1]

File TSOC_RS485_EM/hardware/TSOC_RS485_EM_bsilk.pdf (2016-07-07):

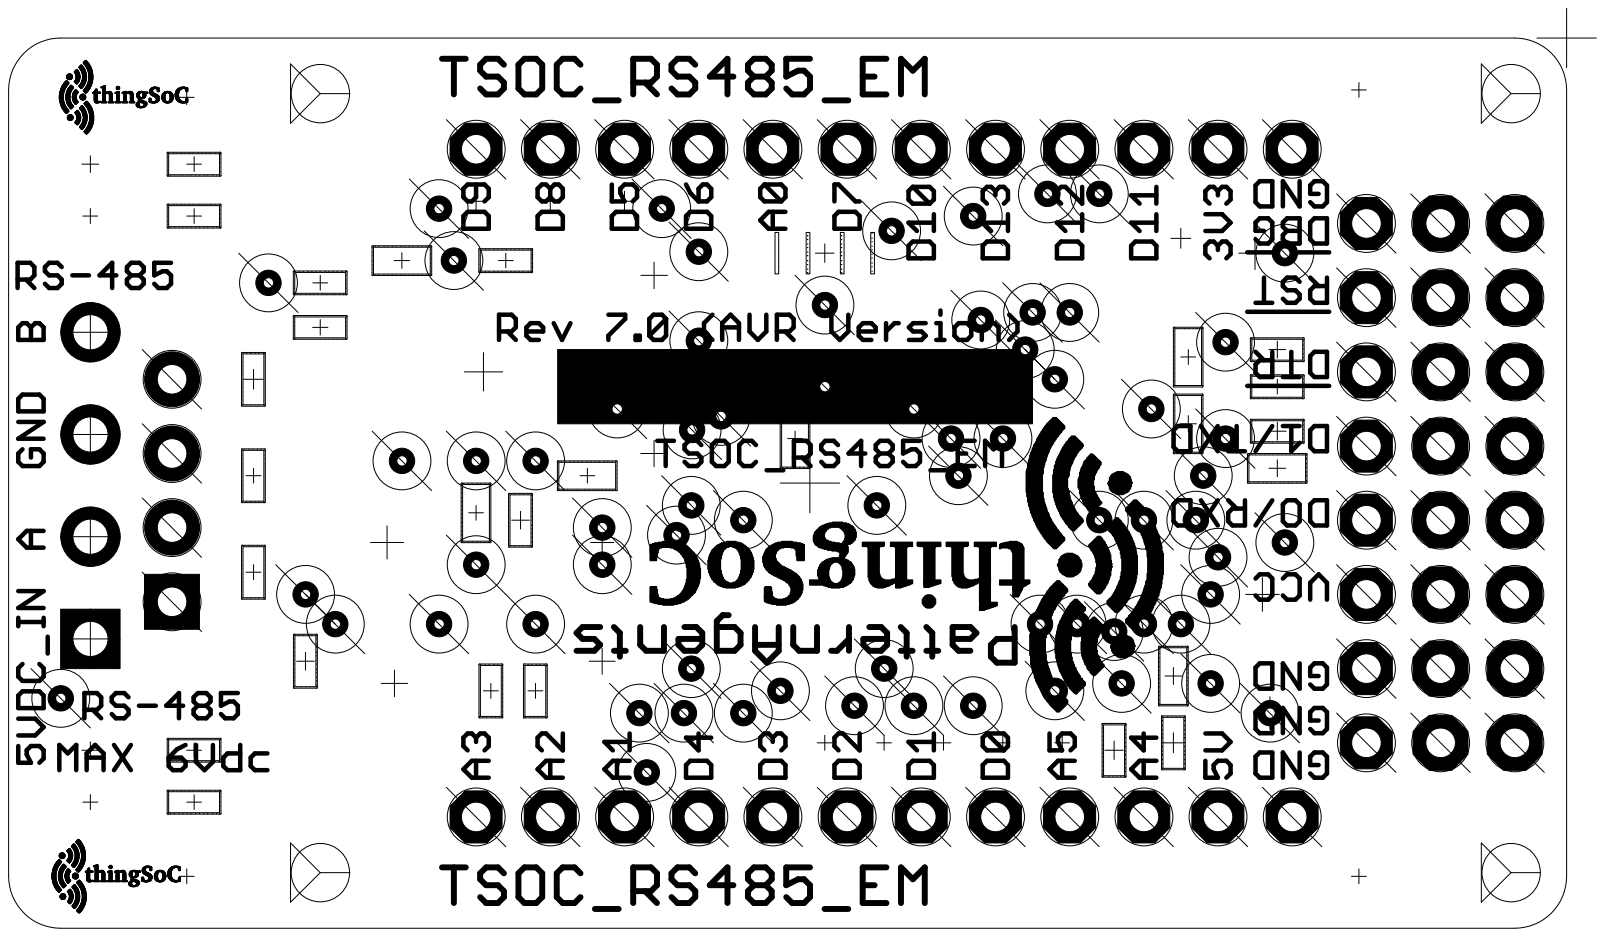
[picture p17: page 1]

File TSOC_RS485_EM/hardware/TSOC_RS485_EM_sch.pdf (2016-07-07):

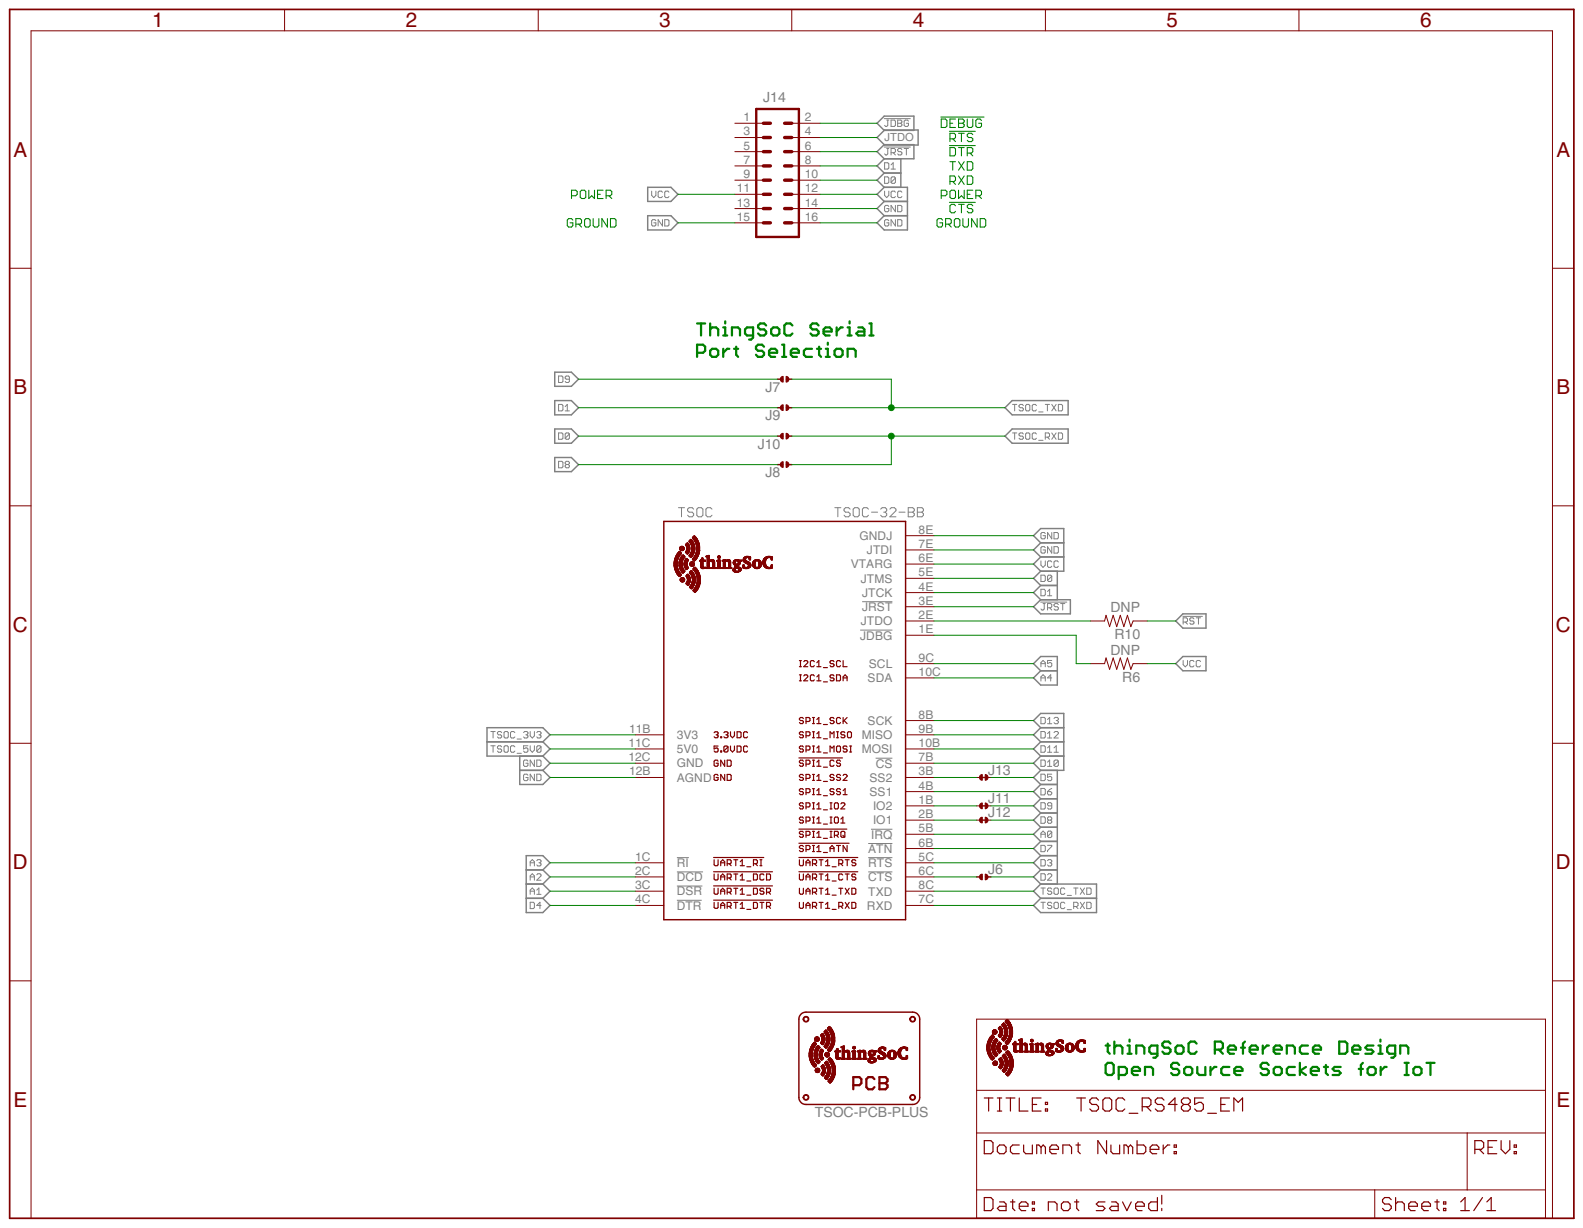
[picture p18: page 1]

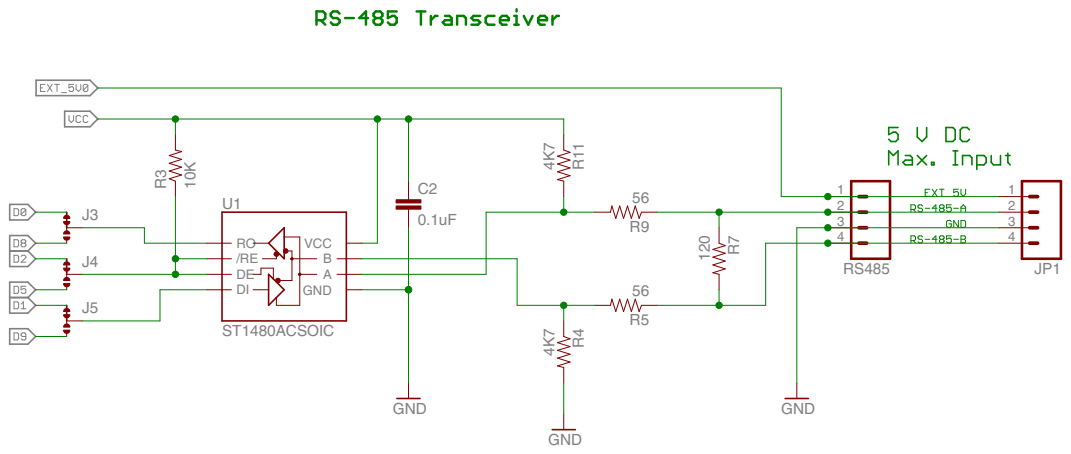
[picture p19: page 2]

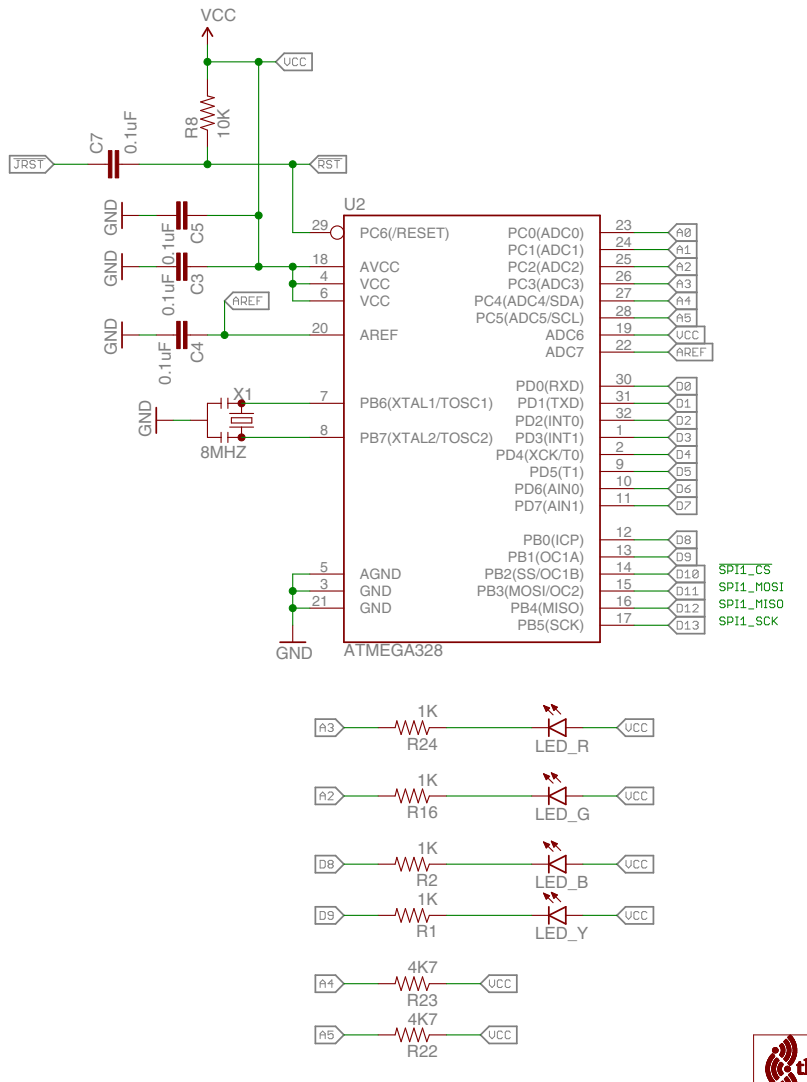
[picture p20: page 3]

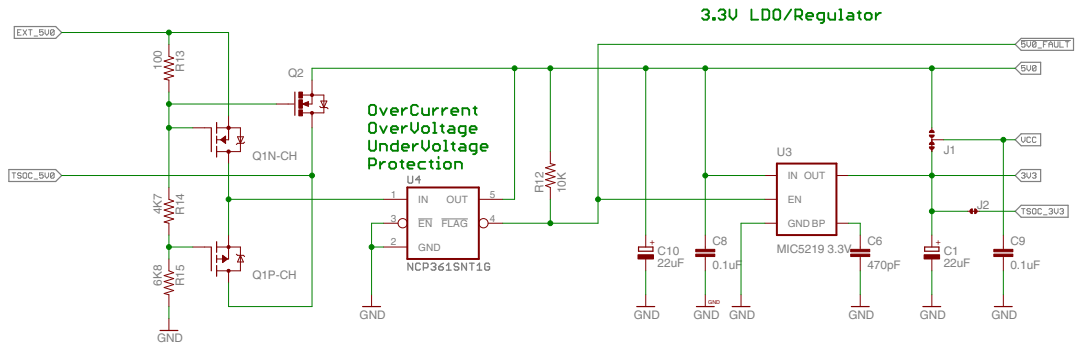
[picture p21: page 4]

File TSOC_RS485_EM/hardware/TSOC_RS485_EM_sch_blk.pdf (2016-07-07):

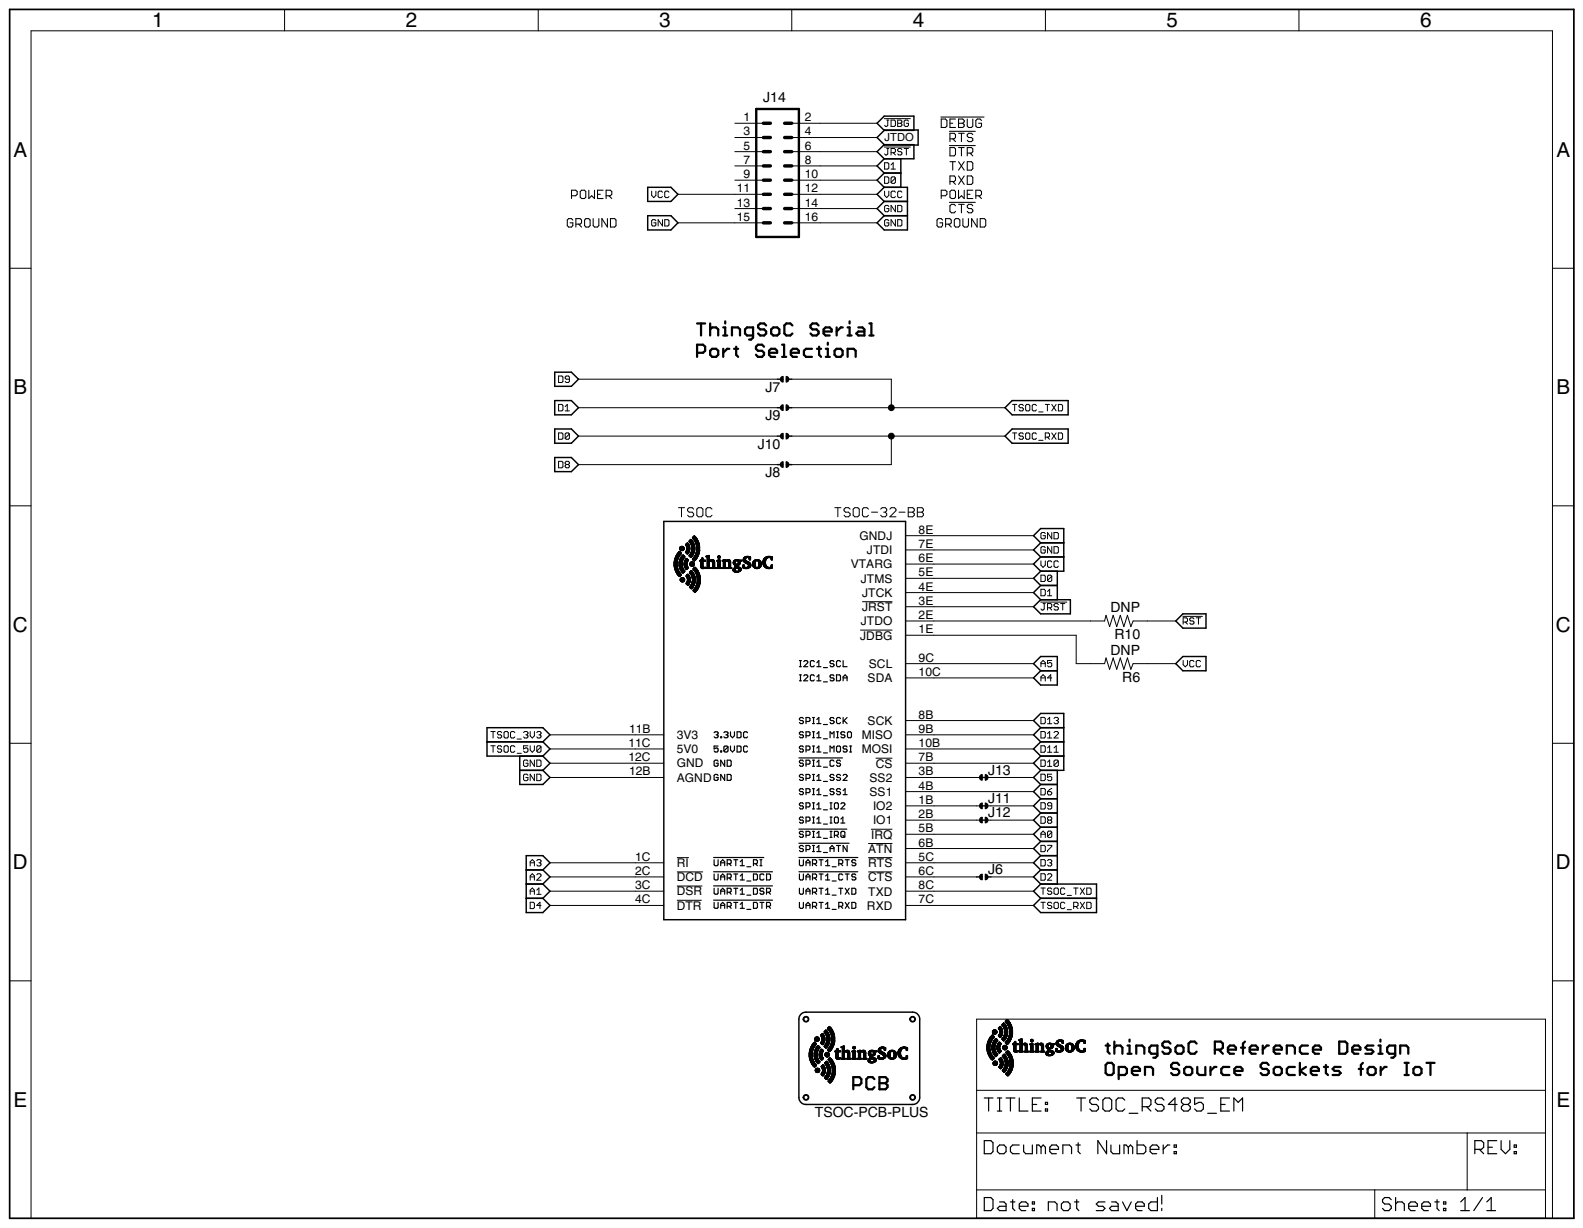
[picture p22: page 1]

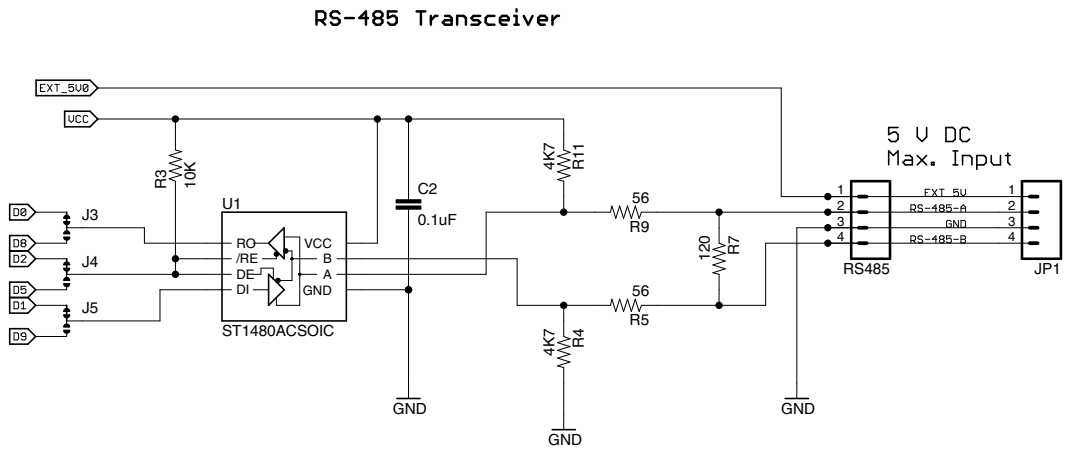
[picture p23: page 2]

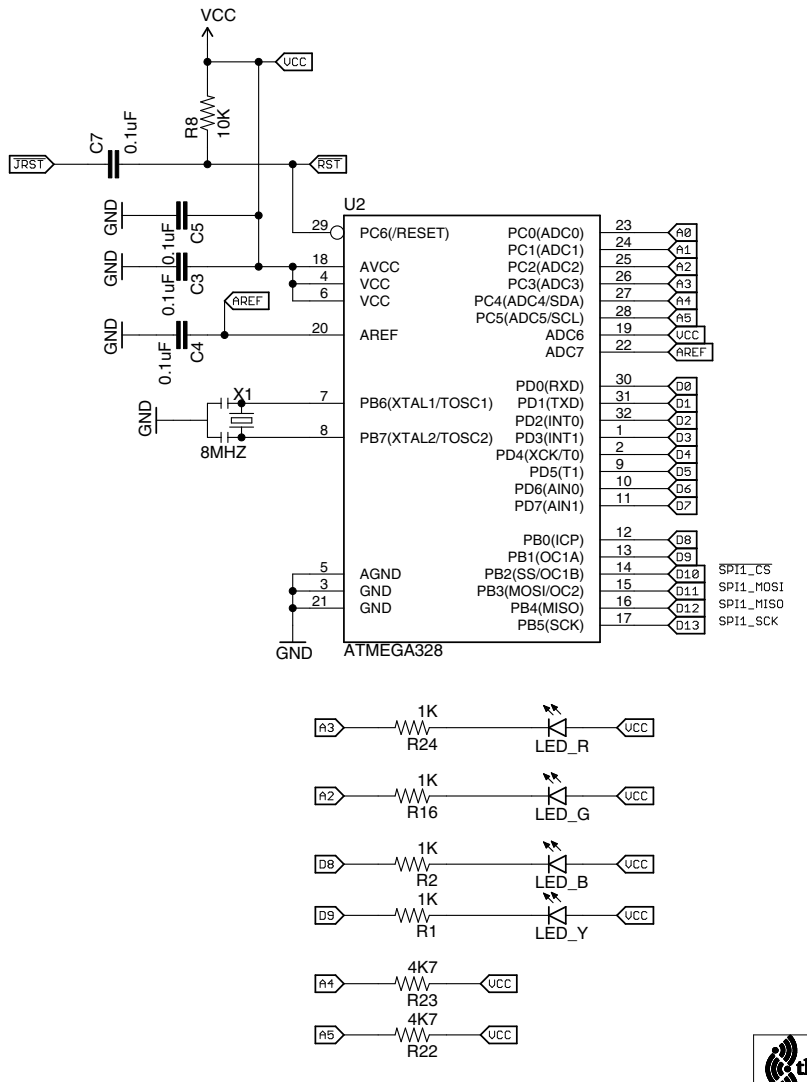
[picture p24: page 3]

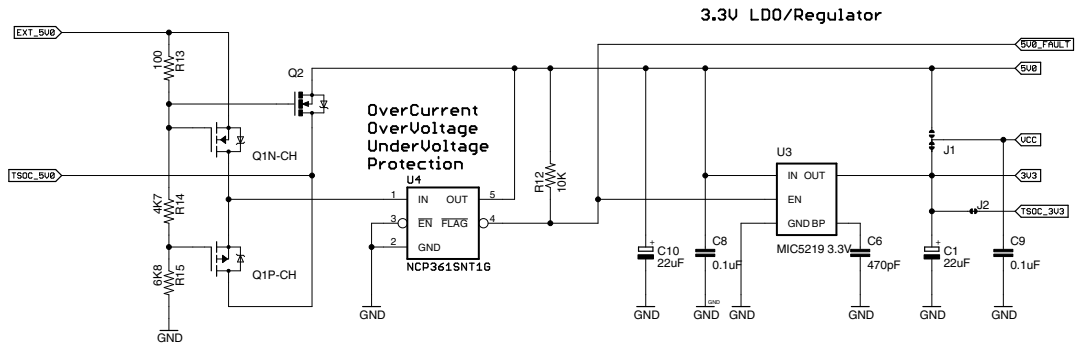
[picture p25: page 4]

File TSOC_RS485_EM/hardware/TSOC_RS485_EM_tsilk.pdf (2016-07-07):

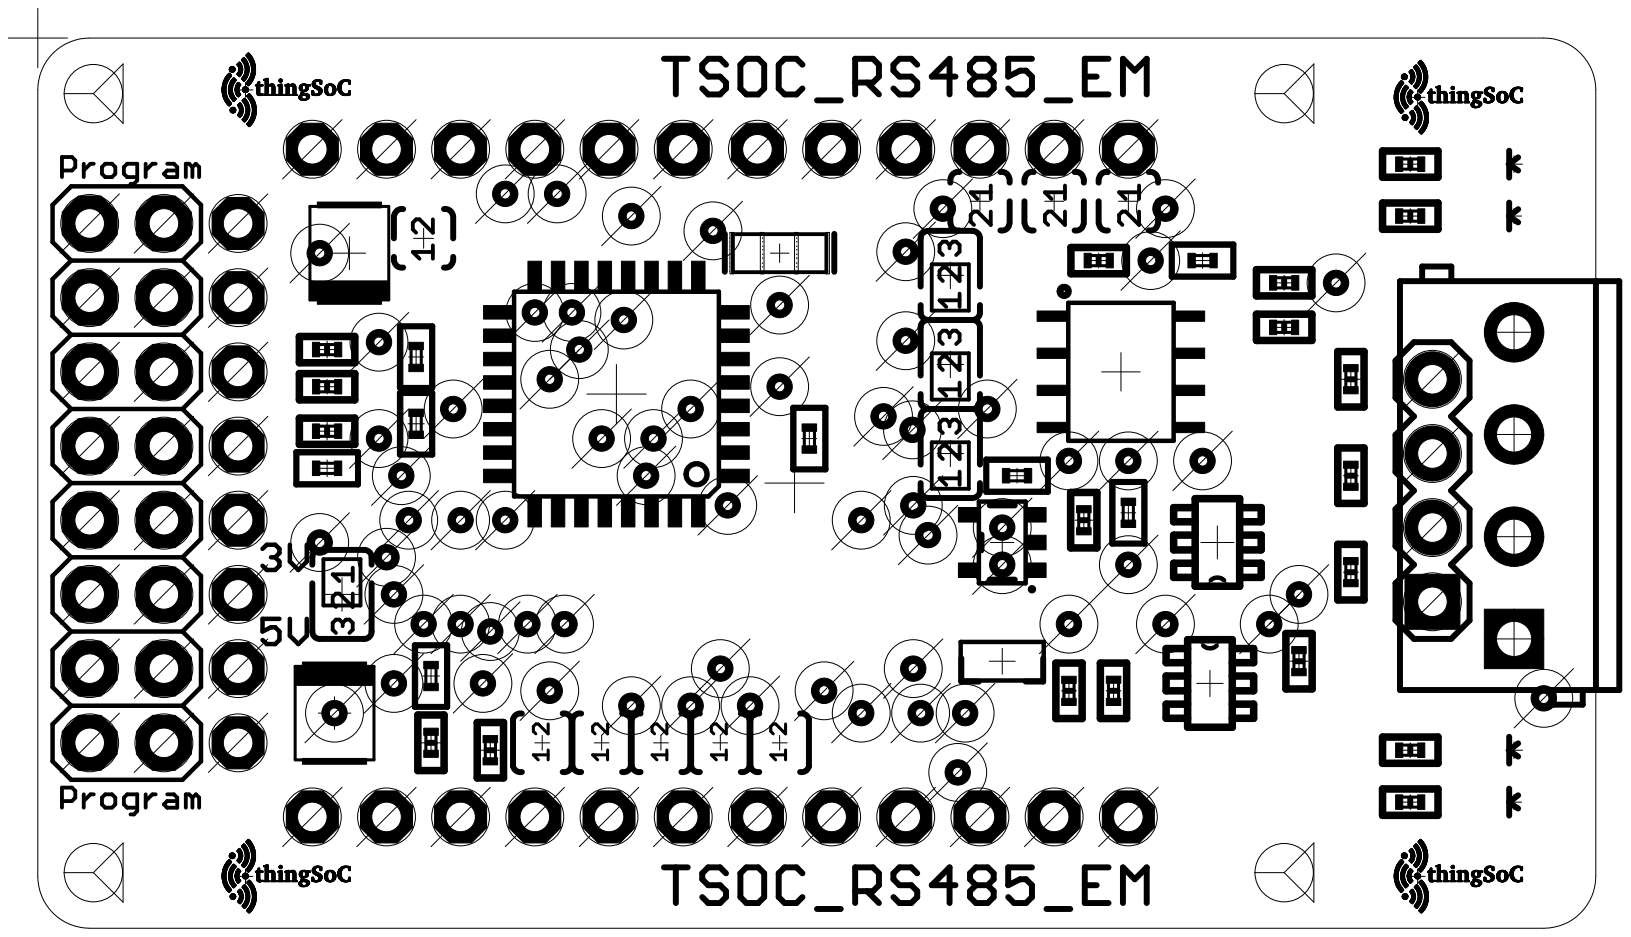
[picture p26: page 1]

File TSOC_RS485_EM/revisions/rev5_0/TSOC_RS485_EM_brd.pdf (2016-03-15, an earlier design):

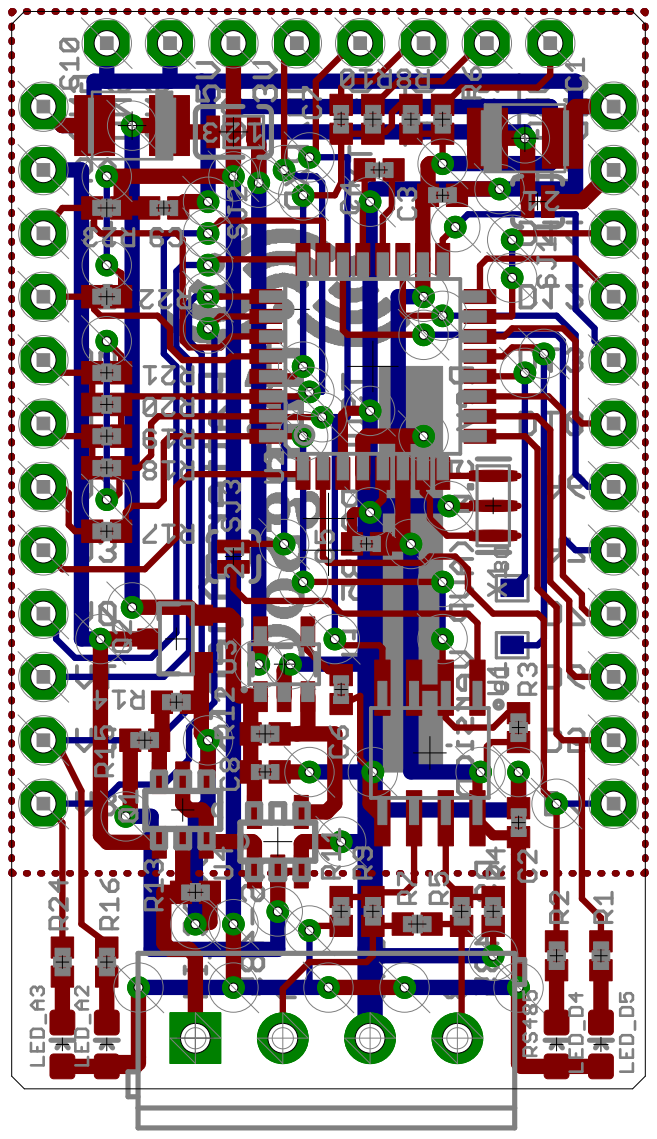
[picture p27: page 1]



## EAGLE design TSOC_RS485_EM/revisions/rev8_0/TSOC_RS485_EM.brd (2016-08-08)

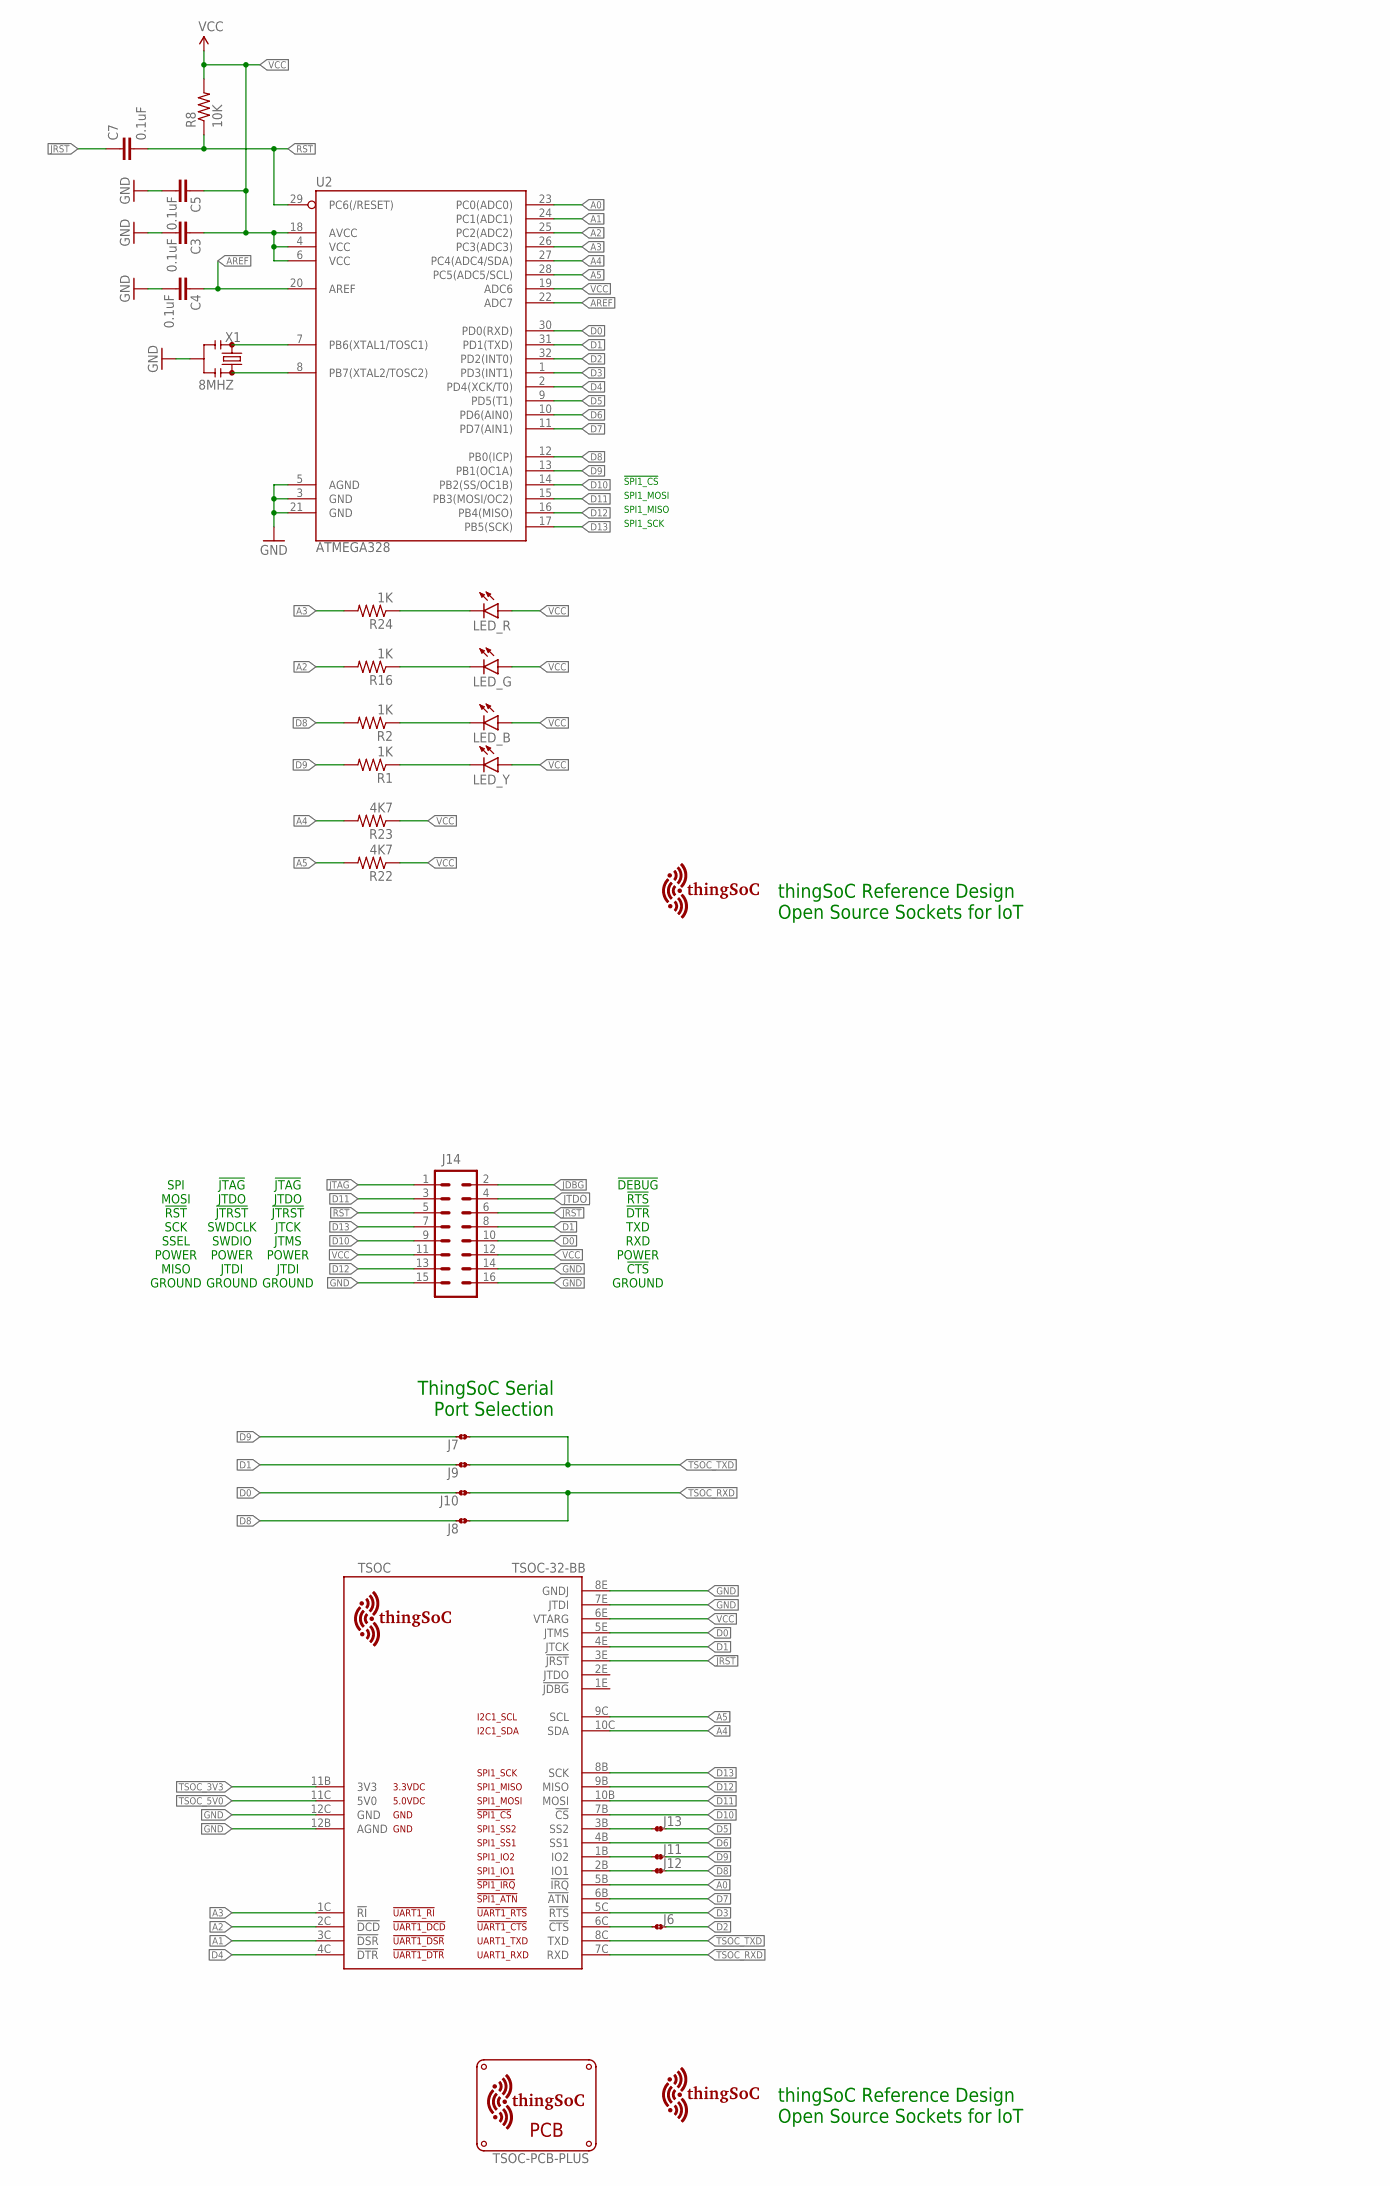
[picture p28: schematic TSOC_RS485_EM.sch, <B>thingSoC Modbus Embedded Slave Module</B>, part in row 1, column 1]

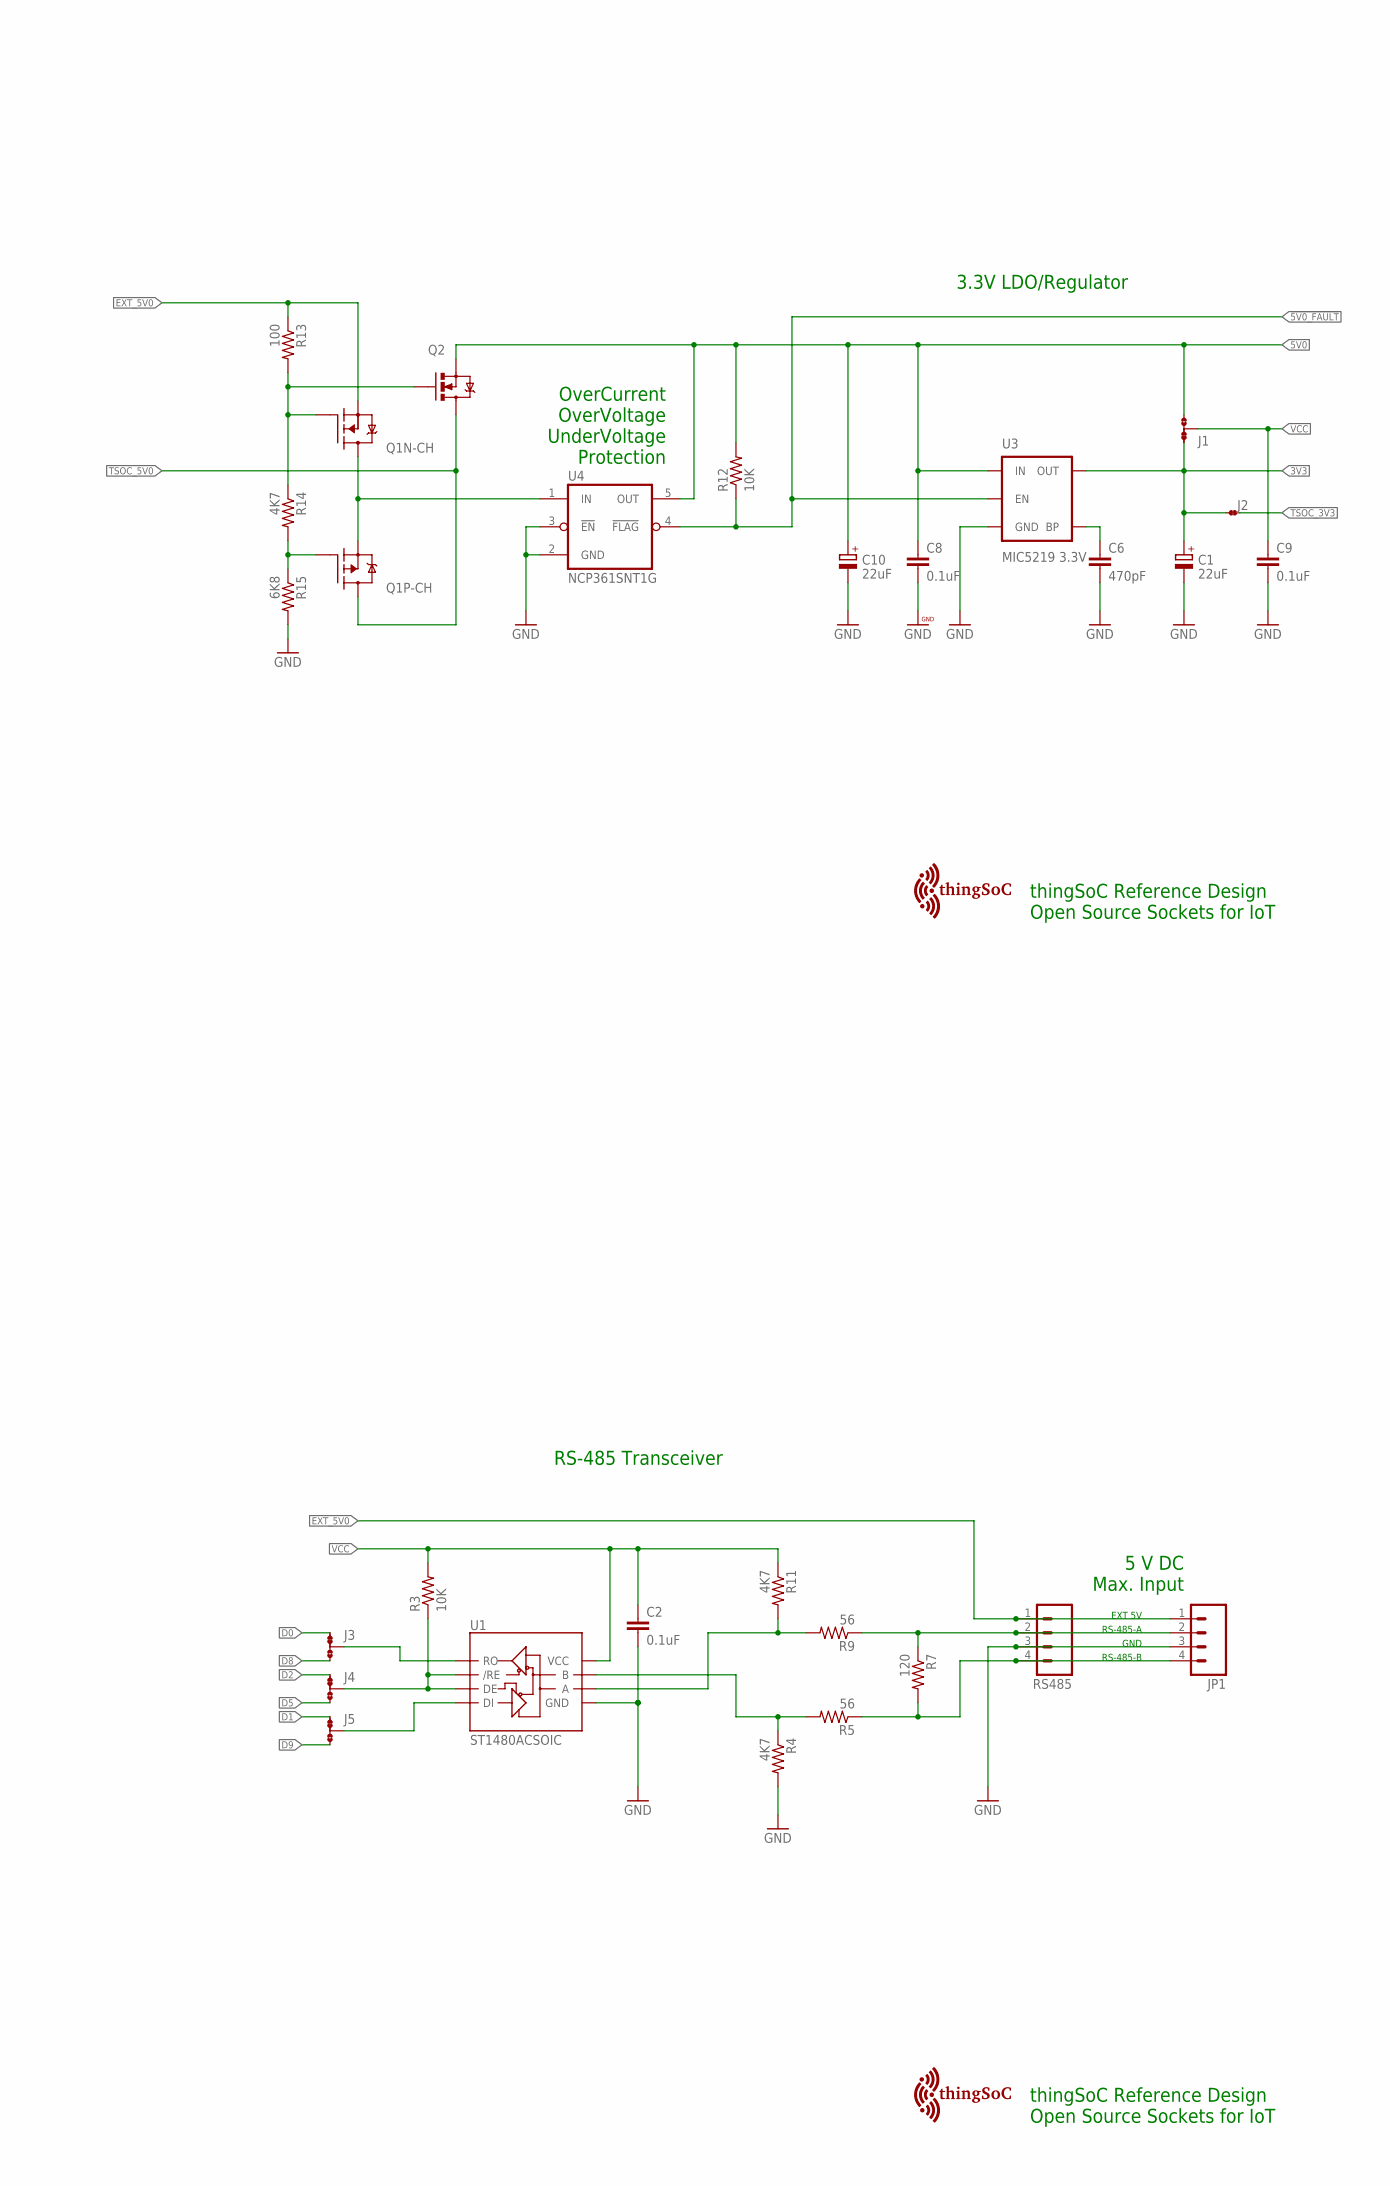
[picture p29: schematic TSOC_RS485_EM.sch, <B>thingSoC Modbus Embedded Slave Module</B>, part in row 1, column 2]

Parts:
C1, C10: 22uF; SMC_B
C2, C3, C4, C5, C7, C8, C9: 0.1uF; EIA-0402
C6: 470pF; EIA-0402
J1, J3, J4, J5: JMP-3-1_2
J2, J11, J12, J13: JMP-2-NC
J6, J7, J8, J9, J10: JMP-2-NO
J14: M08X2; 2X8
JP1: M04PTH; 1X04
LED_B: LED0603; LED-0603
LED_G: LED0603; LED-0603
LED_R: LED0603; LED-0603
LED_Y: LED0603; LED-0603
Q1: FDC6420C; SOT95P280X110-6N
Q2: MOSFET-NCHANNELAO3404A; SOT23-3
R1, R2, R16, R24: 1K; EIA-0402-MIN
R3, R8, R12: 10K; EIA-0402-MIN
R4, R11, R14, R22, R23: 4K7; EIA-0402-MIN
R5, R9: 56; EIA-0402-MIN
R7: 120; EIA-0402-MIN
R13: 100; EIA-0402-MIN
R15: 6K8; EIA-0402-MIN
RS485: M04SCREW; SCREWTERMINAL-3.5MM-4
TSOC: TSOC-32-BB; TSOC-BB-S32
U1: ST1480ACSOIC; SO08
U2: ATMEGA328; TQFP32-08
U3: MIC5219 3.3V; SOT23-5
U4: NCP361SNT1G; SOP95P275X110-5N
U$3: TSOC-PCB-PLUS; TSOC-BB-BRD-PLUS
U$5, U$6, U$7, U$8: TSOC-LOGO-SMALL; TSOC-LOGO-SML
X1: 8MHZ; RESONATOR-SMD

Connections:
3V3: C1.+, J1.1, J2.1, U3.5 (OUT)
5V0: C8.1, C10.+, J1.3, Q2.2 (S), R12.2, U3.1 (IN), U4.5 (OUT)
!5V0_FAULT: R12.1, U3.3 (EN), U4.4 (!FLAG)
!JDBG: J14.2
!JRST: C7.1, J14.6, TSOC.3E (!JRST)
!JTAG: J14.1
!RST: C7.2, J14.5, R8.1, U2.29 (PC6(/RESET))
A: R9.2, R11.2, U1.6 (A)
A0: TSOC.5B (!IRQ), U2.23 (PC0(ADC0))
A1: TSOC.3C (!DSR), U2.24 (PC1(ADC1))
A2: R16.2, TSOC.2C (!DCD), U2.25 (PC2(ADC2))
A3: R24.2, TSOC.1C (!RI), U2.26 (PC3(ADC3))
A4: R23.2, TSOC.10C (SDA), U2.27 (PC4(ADC4/SDA))
A5: R22.2, TSOC.9C (SCL), U2.28 (PC5(ADC5/SCL))
AO: JP1.2, R7.1, R9.1, RS485.2
AREF: C4.2, U2.20 (AREF), U2.22 (ADC7)
B: R4.1, R5.2, U1.7 (B)
BO: JP1.4, R5.1, R7.2, RS485.4
BYPASS1: C6.1, U3.4 (BP)
D0: J3.1, J10.2, J14.10, TSOC.5E (JTMS), U2.30 (PD0(RXD))
D1: J5.1, J9.2, J14.8, TSOC.4E (JTCK), U2.31 (PD1(TXD))
D2: J4.1, J6.2, U2.32 (PD2(INT0))
D3: TSOC.5C (!RTS), U2.1 (PD3(INT1))
D4: TSOC.4C (!DTR), U2.2 (PD4(XCK/T0))
D5: J4.3, J13.2, U2.9 (PD5(T1))
D6: TSOC.4B (SS1), U2.10 (PD6(AIN0))
D7: TSOC.6B (!ATN), U2.11 (PD7(AIN1))
D8: J3.3, J8.2, J12.2, R2.2, U2.12 (PB0(ICP))
D9: J5.3, J7.2, J11.2, R1.2, U2.13 (PB1(OC1A))
D10: J14.9, TSOC.7B (!CS), U2.14 (PB2(SS/OC1B))
D11: J14.3, TSOC.10B (MOSI), U2.15 (PB3(MOSI/OC2))
D12: J14.13, TSOC.9B (MISO), U2.16 (PB4(MISO))
D13: J14.7, TSOC.8B (SCK), U2.17 (PB5(SCK))
DE: J4.2, R3.1, U1.2 (/RE), U1.3 (DE)
DI: J5.2, U1.4 (DI)
EXT_5V0: JP1.1, Q1.5 (S), R13.1, RS485.1
GND: C1.-, C2.2, C3.1, C4.1, C5.1, C6.2, C8.2, C9.2, C10.-, J14.14, J14.15, J14.16, JP1.3, R4.2, R15.2, RS485.3, TSOC.7E (JTDI), TSOC.8E (GNDJ), TSOC.12B (AGND), TSOC.12C (GND), U1.5 (GND), U2.3 (GND), U2.5 (AGND), U2.21 (GND), U3.2 (GND), U4.2 (GND), U4.3 (!EN), X1.2
JTDO: J14.4
LEDB: LED_B.C, R2.1
LEDG: LED_G.C, R16.1
LEDR: LED_R.C, R24.1
LEDY: LED_Y.C, R1.1
unnamed: J13.1, TSOC.3B (SS2)
NGATE: Q1.1 (G), Q2.1 (G), R13.2, R14.1
PGATE: Q1.3 (G), R14.2, R15.1
RXD: J3.2, U1.1 (RO)
TSOC_3V3: J2.2, TSOC.11B (3V3)
TSOC_5V0: Q1.4 (D), Q2.3 (D), TSOC.11C (5V0)
TSOC_CTS: J6.1, TSOC.6C (!CTS)
TSOC_D8: J12.1, TSOC.2B (IO1)
TSOC_D9: J11.1, TSOC.1B (IO2)
TSOC_RXD: J8.1, J10.1, TSOC.7C (RXD)
TSOC_TXD: J7.1, J9.1, TSOC.8C (TXD)
VCC: C2.1, C3.2, C5.2, C9.1, J1.2, J14.11, J14.12, LED_B.A, LED_G.A, LED_R.A, LED_Y.A, R3.2, R8.2, R11.1, R22.1, R23.1, TSOC.6E (VTARG), U1.8 (VCC), U2.4 (VCC), U2.6 (VCC), U2.18 (AVCC), U2.19 (ADC6)
VIN: Q1.2 (S), Q1.6 (D), U4.1 (IN)
XIN: U2.7 (PB6(XTAL1/TOSC1)), X1.3
XOUT: U2.8 (PB7(XTAL2/TOSC2)), X1.1

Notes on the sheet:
SPI1_SCK
SPI1_MISO
SPI1_MOSI
!SPI1_CS
5 V DC Max. Input
OverCurrent OverVoltage UnderVoltage Protection
3.3V LDO/Regulator
RS-485 Transceiver
EXT 5V
GND
RS-485-A
RS-485-B
ThingSoC Serial Port Selection
thingSoC Reference Design Open Source Sockets for IoT
!DEBUG
!RTS
!CTS
!DTR
TXD
RXD
POWER
GROUND
JTDI
JTDO
!JTRST
JTCK
JTMS
!JTAG
SWDCLK
SWDIO
SCK
SSEL
SPI
MOSI
!RST
MISO

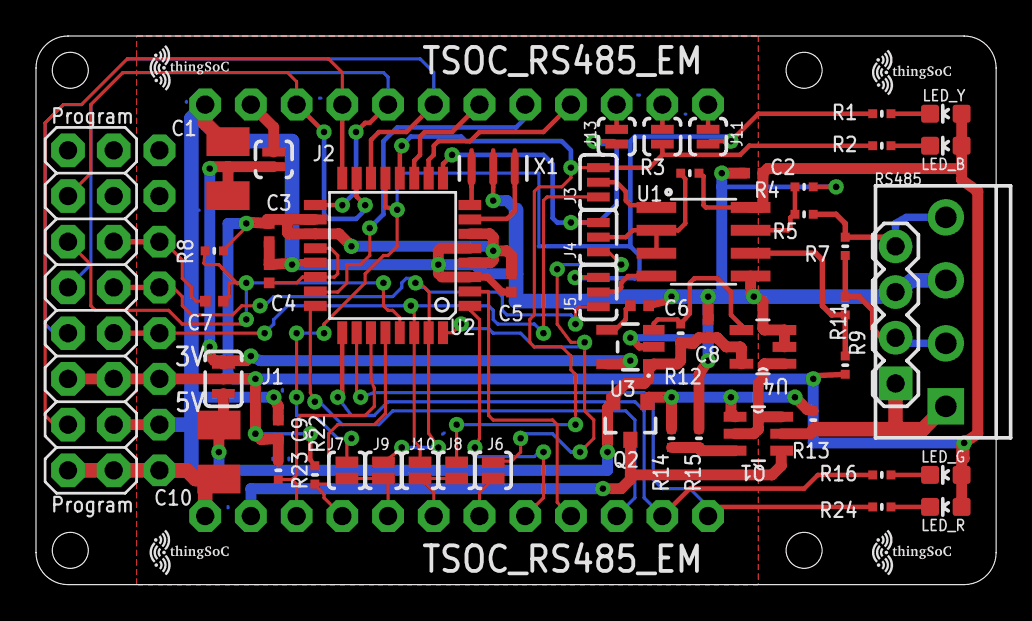
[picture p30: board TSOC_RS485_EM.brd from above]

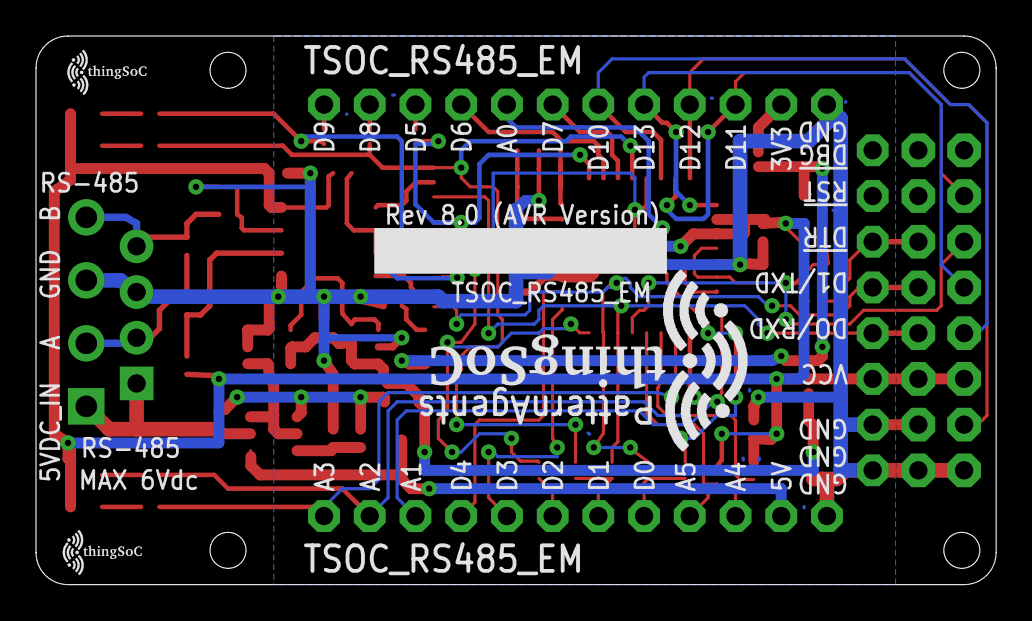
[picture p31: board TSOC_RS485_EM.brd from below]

Board: 2 copper layers, 53.3 x 30.5 mm, 63 parts (3 on the bottom side), 54 nets.

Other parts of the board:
U$1, U$4: TSOC-LOGO-SMALL; TSOC-LOGO-SML
U$100: TSOC-LOGO-LRG

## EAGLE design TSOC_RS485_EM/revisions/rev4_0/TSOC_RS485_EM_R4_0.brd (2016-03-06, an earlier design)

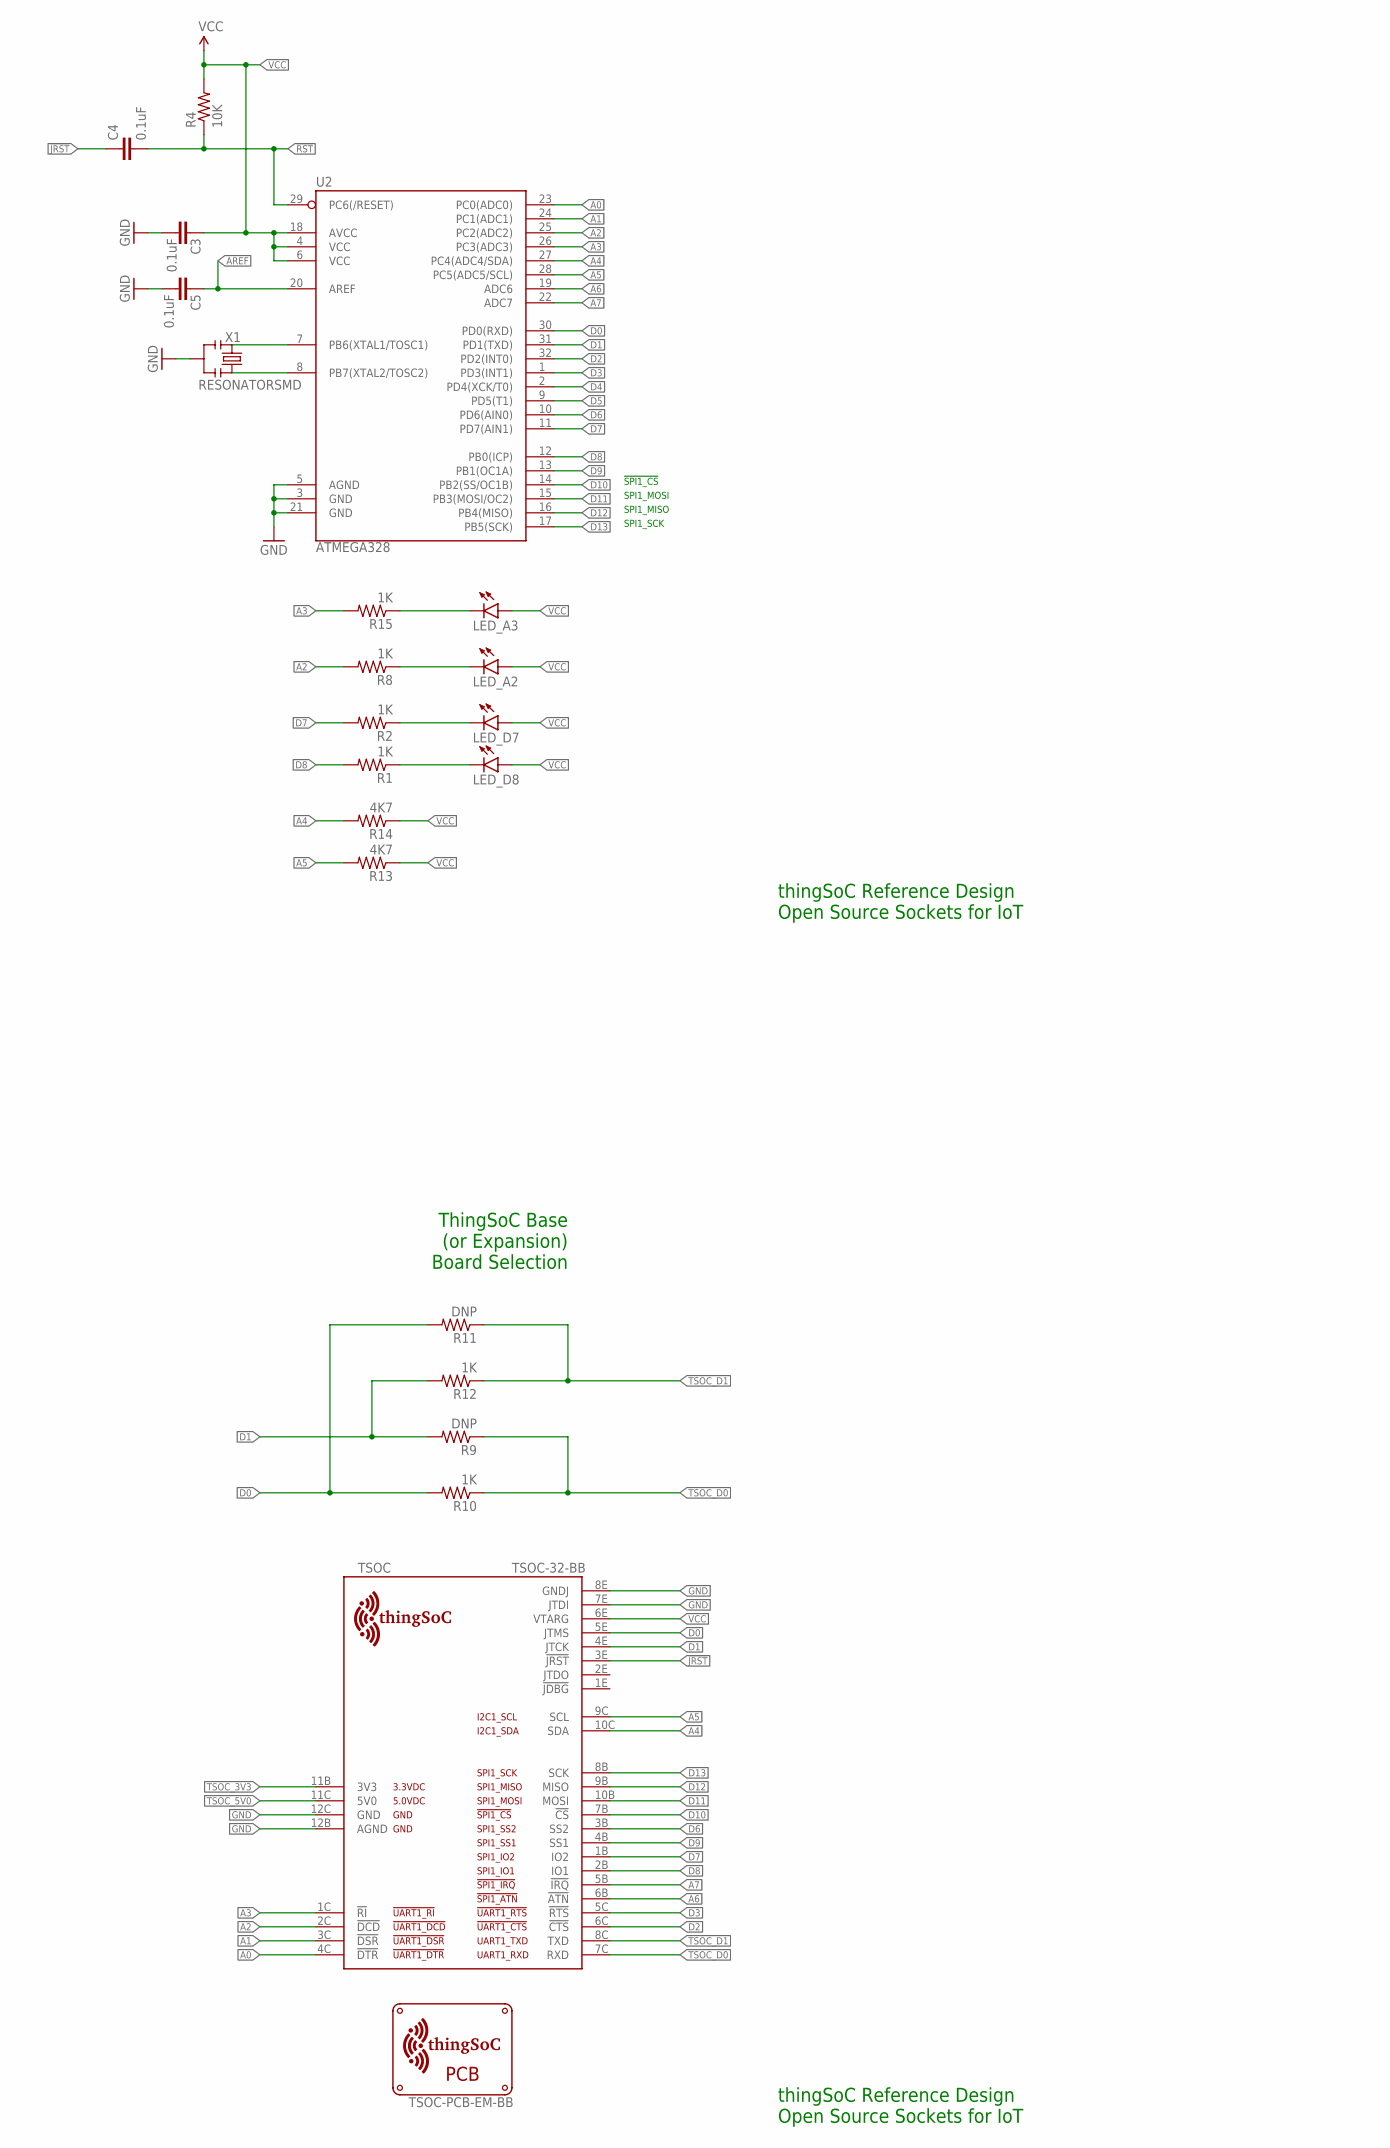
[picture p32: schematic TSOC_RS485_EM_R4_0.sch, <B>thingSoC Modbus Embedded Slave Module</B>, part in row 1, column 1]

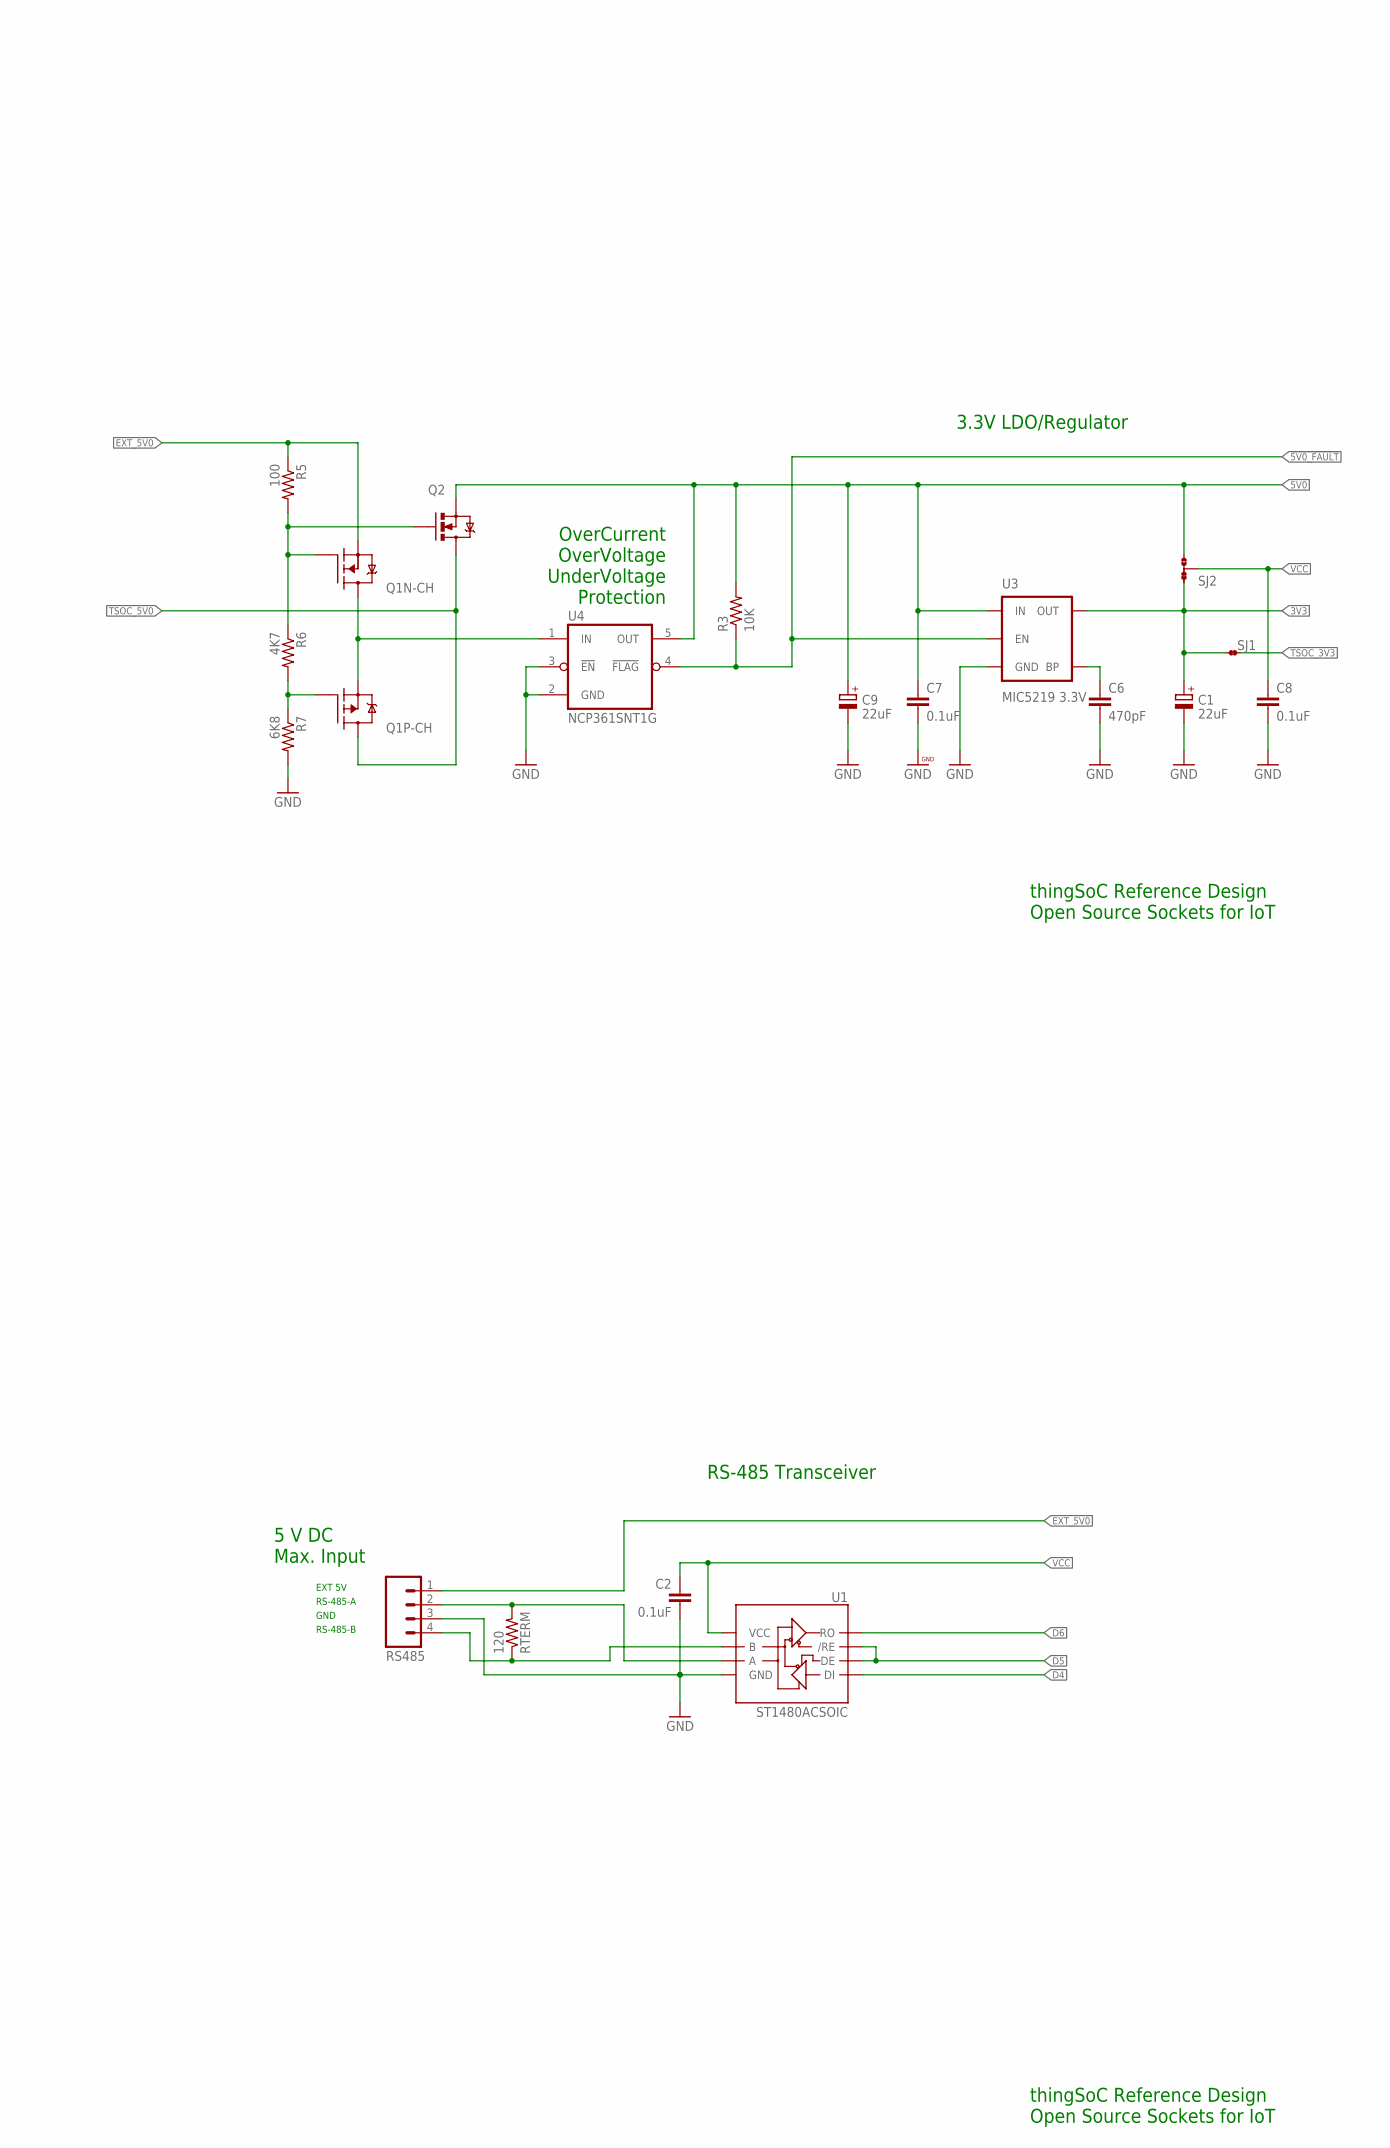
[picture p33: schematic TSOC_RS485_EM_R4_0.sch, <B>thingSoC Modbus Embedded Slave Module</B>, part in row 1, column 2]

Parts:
C1, C9: 22uF; SMC_B
C2, C3, C4, C5, C7, C8: 0.1uF; 0402-CAP
C6: 470pF; 0402-CAP
LED_A2, LED_A3: LED0603; LED-0603
LED_D7, LED_D8: LED0603; LED-0603
Q1: FDC6420C; SOT95P280X110-6N
Q2: MOSFET-NCHANNELAO3404A; SOT23-3
R1, R2, R8, R10, R12, R15: 1K; 0402-RES
R3, R4: 10K; 0402-RES
R5: 100; 0402-RES
R6, R13, R14: 4K7; 0402-RES
R7: 6K8; 0402-RES
R9, R11: DNP; 0402-RES
RS485: M04SCREW; SCREWTERMINAL-3.5MM-4
RTERM: 120; 0402-RES
SJ1: JMP-2-NC
SJ2: JMP-3-1_2
TSOC: TSOC-32-BB; TSOC-BB-S32
U1: ST1480ACSOIC; SO08
U2: ATMEGA328; TQFP32-08
U3: MIC5219 3.3V; SOT23-5
U4: NCP361SNT1G; SOP95P275X110-5N
U$1: TSOC-PCB-EM-BB; TSOC-EM-BB
X1: RESONATORSMD; RESONATOR-SMD

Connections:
3V3: C1.+, SJ1.1, SJ2.1, U3.5 (OUT)
5V0: C7.1, C9.+, Q2.2 (S), R3.2, SJ2.3, U3.1 (IN), U4.5 (OUT)
!5V0_FAULT: R3.1, U3.3 (EN), U4.4 (!FLAG)
!JRST: C4.1, TSOC.3E (!JRST)
!RST: C4.2, R4.1, U2.29 (PC6(/RESET))
A: RS485.4, RTERM.1, U1.7 (B)
A0: TSOC.4C (!DTR), U2.23 (PC0(ADC0))
A1: TSOC.3C (!DSR), U2.24 (PC1(ADC1))
A2: R8.2, TSOC.2C (!DCD), U2.25 (PC2(ADC2))
A3: R15.2, TSOC.1C (!RI), U2.26 (PC3(ADC3))
A4: R14.2, TSOC.10C (SDA), U2.27 (PC4(ADC4/SDA))
A5: R13.2, TSOC.9C (SCL), U2.28 (PC5(ADC5/SCL))
A6: TSOC.6B (!ATN), U2.19 (ADC6)
A7: TSOC.5B (!IRQ), U2.22 (ADC7)
AREF: C5.2, U2.20 (AREF)
B: RS485.2, RTERM.2, U1.6 (A)
BYPASS1: C6.1, U3.4 (BP)
D0: R10.2, R11.2, TSOC.5E (JTMS), U2.30 (PD0(RXD))
D1: R9.2, R12.2, TSOC.4E (JTCK), U2.31 (PD1(TXD))
D2: TSOC.6C (!CTS), U2.32 (PD2(INT0))
D3: TSOC.5C (!RTS), U2.1 (PD3(INT1))
D4: U1.4 (DI), U2.2 (PD4(XCK/T0))
D5: U1.2 (/RE), U1.3 (DE), U2.9 (PD5(T1))
D6: TSOC.3B (SS2), U1.1 (RO), U2.10 (PD6(AIN0))
D7: R2.2, TSOC.1B (IO2), U2.11 (PD7(AIN1))
D8: R1.2, TSOC.2B (IO1), U2.12 (PB0(ICP))
D9: TSOC.4B (SS1), U2.13 (PB1(OC1A))
D10: TSOC.7B (!CS), U2.14 (PB2(SS/OC1B))
D11: TSOC.10B (MOSI), U2.15 (PB3(MOSI/OC2))
D12: TSOC.9B (MISO), U2.16 (PB4(MISO))
D13: TSOC.8B (SCK), U2.17 (PB5(SCK))
EXT_5V0: Q1.5 (S), R5.1, RS485.1
GND: C1.-, C2.2, C3.1, C5.1, C6.2, C7.2, C8.2, C9.-, R7.2, RS485.3, TSOC.7E (JTDI), TSOC.8E (GNDJ), TSOC.12B (AGND), TSOC.12C (GND), U1.5 (GND), U2.3 (GND), U2.5 (AGND), U2.21 (GND), U3.2 (GND), U4.2 (GND), U4.3 (!EN), X1.2
LED_A2: LED_A2.C, R8.1
unnamed: LED_D7.C, R2.1
unnamed: LED_A3.C, R15.1
unnamed: LED_D8.C, R1.1
NGATE: Q1.1 (G), Q2.1 (G), R5.2, R6.1
PGATE: Q1.3 (G), R6.2, R7.1
TSOC_3V3: SJ1.2, TSOC.11B (3V3)
TSOC_5V0: Q1.4 (D), Q2.3 (D), TSOC.11C (5V0)
TSOC_D0: R9.1, R10.1, TSOC.7C (RXD)
TSOC_D1: R11.1, R12.1, TSOC.8C (TXD)
VCC: C2.1, C3.2, C8.1, LED_A2.A, LED_A3.A, LED_D7.A, LED_D8.A, R4.2, R13.1, R14.1, SJ2.2, TSOC.6E (VTARG), U1.8 (VCC), U2.4 (VCC), U2.6 (VCC), U2.18 (AVCC)
VIN: Q1.2 (S), Q1.6 (D), U4.1 (IN)
XIN: U2.7 (PB6(XTAL1/TOSC1)), X1.3
XOUT: U2.8 (PB7(XTAL2/TOSC2)), X1.1

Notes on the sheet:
SPI1_SCK
SPI1_MISO
SPI1_MOSI
!SPI1_CS
5 V DC Max. Input
OverCurrent OverVoltage UnderVoltage Protection
3.3V LDO/Regulator
RS-485 Transceiver
EXT 5V
GND
RS-485-A
RS-485-B
ThingSoC Base (or Expansion) Board Selection
thingSoC Reference Design Open Source Sockets for IoT

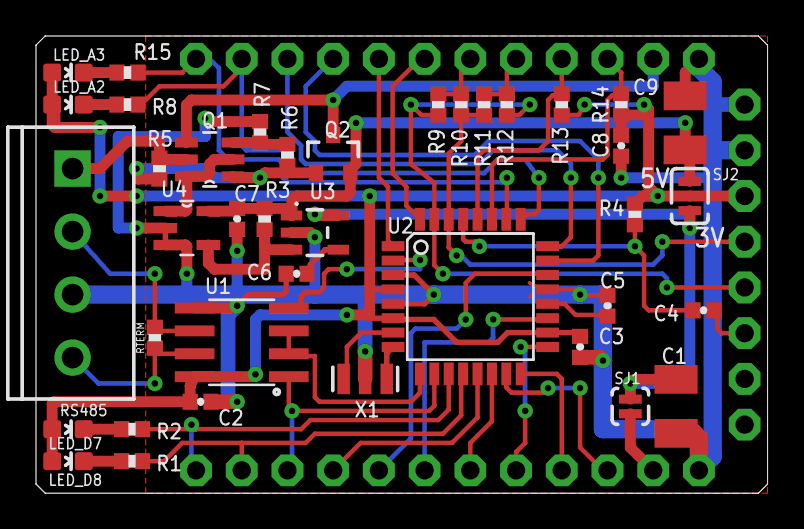
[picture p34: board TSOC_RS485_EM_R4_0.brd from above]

Board: 2 copper layers, 40.6 x 25.4 mm, 42 parts (1 on the bottom side), 47 nets.

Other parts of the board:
U$100: TSOC-LOGO-LRG

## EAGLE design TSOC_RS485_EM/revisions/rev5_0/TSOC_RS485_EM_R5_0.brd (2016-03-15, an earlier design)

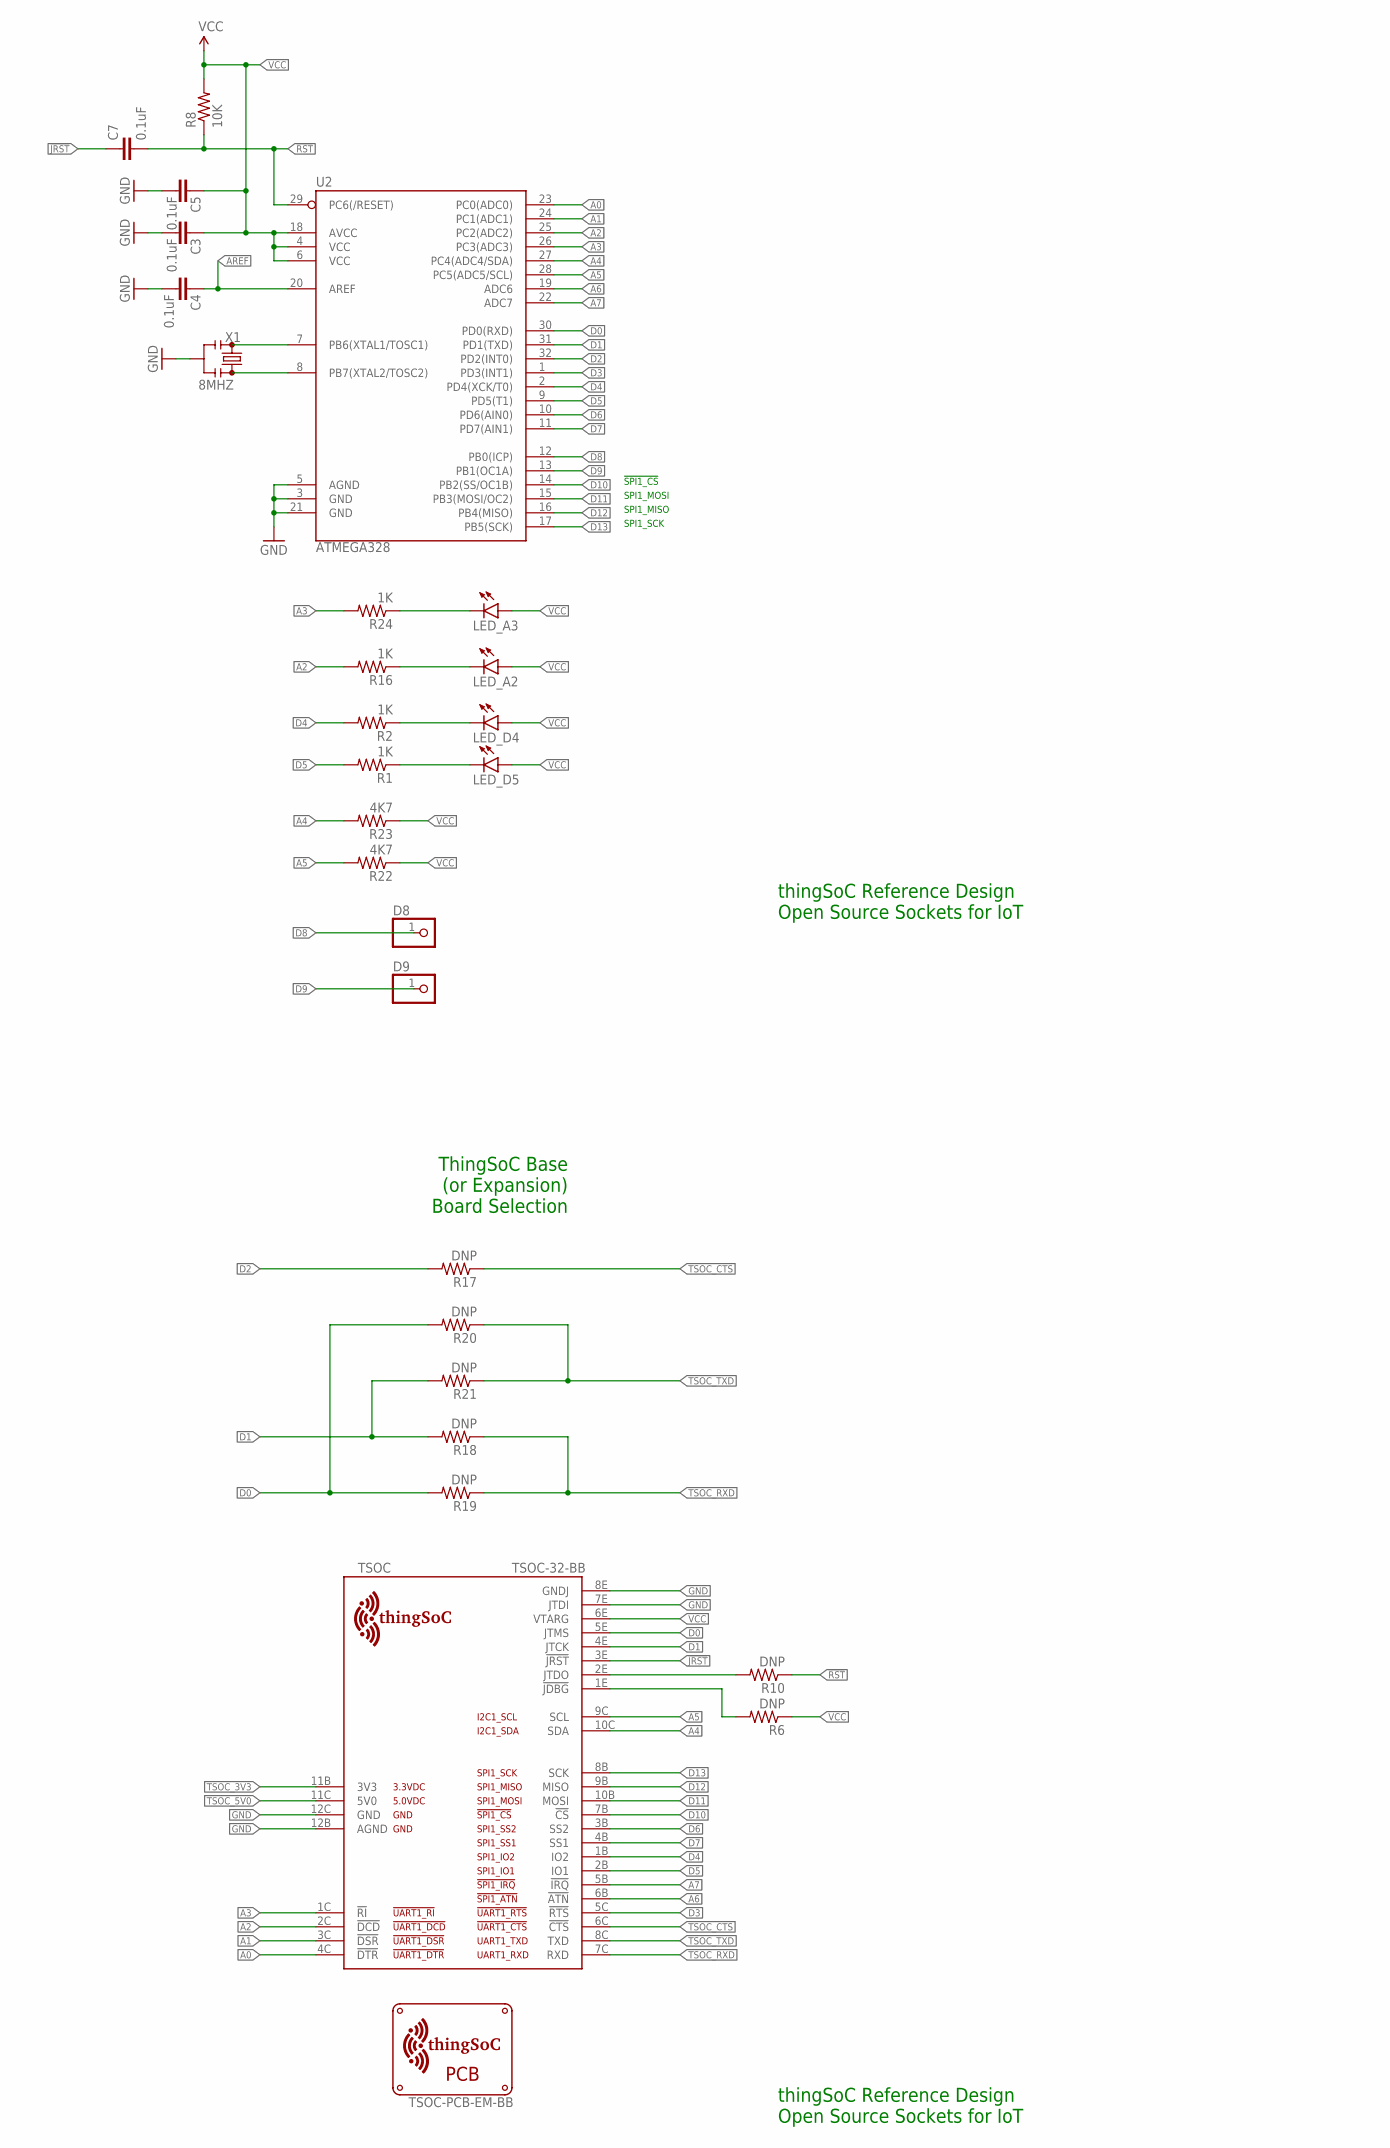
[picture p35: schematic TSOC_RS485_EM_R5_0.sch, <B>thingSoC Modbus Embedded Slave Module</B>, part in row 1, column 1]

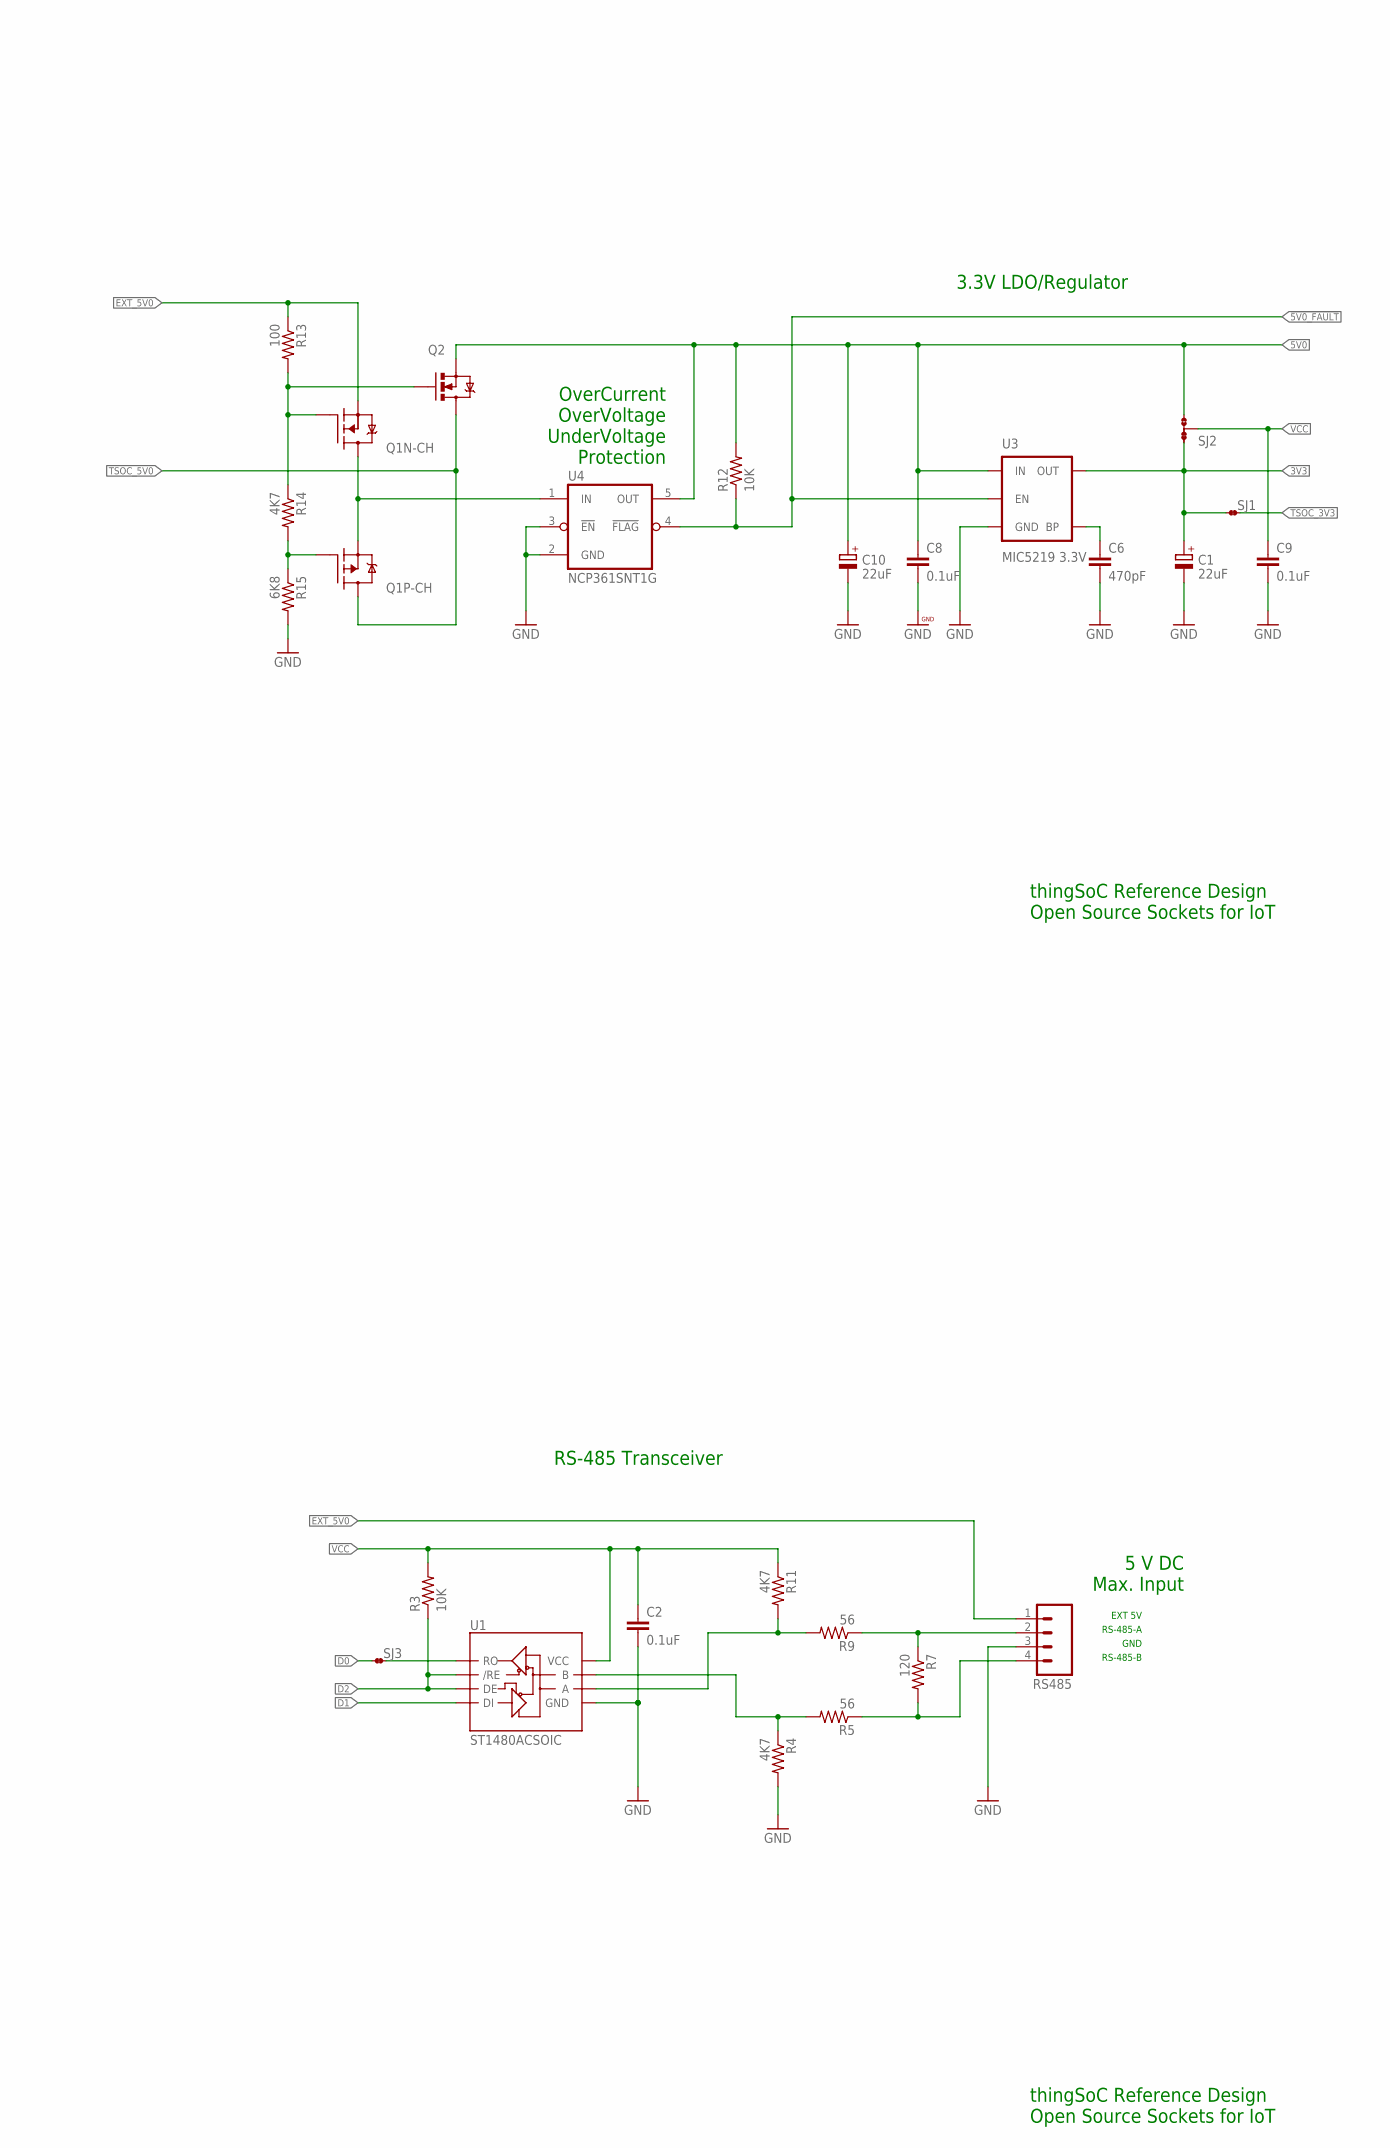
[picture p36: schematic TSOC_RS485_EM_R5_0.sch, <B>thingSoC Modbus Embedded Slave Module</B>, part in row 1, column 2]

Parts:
C1, C10: 22uF; SMC_B
C2, C3, C4, C5, C7, C8, C9: 0.1uF; 0402-CAP
C6: 470pF; 0402-CAP
D8, D9: WPAD-1-0402
LED_A2, LED_A3: LED0603; LED-0603
LED_D4, LED_D5: LED0603; LED-0603
Q1: FDC6420C; SOT95P280X110-6N
Q2: MOSFET-NCHANNELAO3404A; SOT23-3
R1, R2, R16, R24: 1K; 0402-RES
R3, R8, R12: 10K; 0402-RES
R4, R11, R14, R22, R23: 4K7; 0402-RES
R5, R9: 56; 0402-RES
R6, R10, R17, R18, R19, R20, R21: DNP; 0402-RES
R7: 120; 0402-RES
R13: 100; 0402-RES
R15: 6K8; 0402-RES
RS485: M04SCREW; SCREWTERMINAL-3.5MM-4
SJ1, SJ3: JMP-2-NC
SJ2: JMP-3-1_2
TSOC: TSOC-32-BB; TSOC-BB-S32
U1: ST1480ACSOIC; SO08
U2: ATMEGA328; TQFP32-08
U3: MIC5219 3.3V; SOT23-5
U4: NCP361SNT1G; SOP95P275X110-5N
U$1: TSOC-PCB-EM-BB; TSOC-EM-BB
X1: 8MHZ; RESONATOR-SMD

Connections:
3V3: C1.+, SJ1.1, SJ2.1, U3.5 (OUT)
5V0: C8.1, C10.+, Q2.2 (S), R12.2, SJ2.3, U3.1 (IN), U4.5 (OUT)
!5V0_FAULT: R12.1, U3.3 (EN), U4.4 (!FLAG)
!JDBG: R6.2, TSOC.1E (!JDBG)
!JRST: C7.1, TSOC.3E (!JRST)
!RST: C7.2, R8.1, R10.1, U2.29 (PC6(/RESET))
A: R9.2, R11.2, U1.6 (A)
A0: TSOC.4C (!DTR), U2.23 (PC0(ADC0))
A1: TSOC.3C (!DSR), U2.24 (PC1(ADC1))
A2: R16.2, TSOC.2C (!DCD), U2.25 (PC2(ADC2))
A3: R24.2, TSOC.1C (!RI), U2.26 (PC3(ADC3))
A4: R23.2, TSOC.10C (SDA), U2.27 (PC4(ADC4/SDA))
A5: R22.2, TSOC.9C (SCL), U2.28 (PC5(ADC5/SCL))
A6: TSOC.6B (!ATN), U2.19 (ADC6)
A7: TSOC.5B (!IRQ), U2.22 (ADC7)
AO: R7.1, R9.1, RS485.2
AREF: C4.2, U2.20 (AREF)
B: R4.1, R5.2, U1.7 (B)
BO: R5.1, R7.2, RS485.4
BYPASS1: C6.1, U3.4 (BP)
D0: R19.2, R20.2, SJ3.1, TSOC.5E (JTMS), U2.30 (PD0(RXD))
D1: R18.2, R21.2, TSOC.4E (JTCK), U1.4 (DI), U2.31 (PD1(TXD))
D2: R3.1, R17.2, U1.2 (/RE), U1.3 (DE), U2.32 (PD2(INT0))
D3: TSOC.5C (!RTS), U2.1 (PD3(INT1))
D4: R2.2, TSOC.1B (IO2), U2.2 (PD4(XCK/T0))
D5: R1.2, TSOC.2B (IO1), U2.9 (PD5(T1))
D6: TSOC.3B (SS2), U2.10 (PD6(AIN0))
D7: TSOC.4B (SS1), U2.11 (PD7(AIN1))
D8: D8.1, U2.12 (PB0(ICP))
D9: D9.1, U2.13 (PB1(OC1A))
D10: TSOC.7B (!CS), U2.14 (PB2(SS/OC1B))
D11: TSOC.10B (MOSI), U2.15 (PB3(MOSI/OC2))
D12: TSOC.9B (MISO), U2.16 (PB4(MISO))
D13: TSOC.8B (SCK), U2.17 (PB5(SCK))
EXT_5V0: Q1.5 (S), R13.1, RS485.1
GND: C1.-, C2.2, C3.1, C4.1, C5.1, C6.2, C8.2, C9.2, C10.-, R4.2, R15.2, RS485.3, TSOC.7E (JTDI), TSOC.8E (GNDJ), TSOC.12B (AGND), TSOC.12C (GND), U1.5 (GND), U2.3 (GND), U2.5 (AGND), U2.21 (GND), U3.2 (GND), U4.2 (GND), U4.3 (!EN), X1.2
JTDO: R10.2, TSOC.2E (JTDO)
LEDB: LED_D4.C, R2.1
LEDG: LED_A2.C, R16.1
LEDR: LED_A3.C, R24.1
LEDY: LED_D5.C, R1.1
NGATE: Q1.1 (G), Q2.1 (G), R13.2, R14.1
PGATE: Q1.3 (G), R14.2, R15.1
RXD: SJ3.2, U1.1 (RO)
TSOC_3V3: SJ1.2, TSOC.11B (3V3)
TSOC_5V0: Q1.4 (D), Q2.3 (D), TSOC.11C (5V0)
TSOC_CTS: R17.1, TSOC.6C (!CTS)
TSOC_RXD: R18.1, R19.1, TSOC.7C (RXD)
TSOC_TXD: R20.1, R21.1, TSOC.8C (TXD)
VCC: C2.1, C3.2, C5.2, C9.1, LED_A2.A, LED_A3.A, LED_D4.A, LED_D5.A, R3.2, R6.1, R8.2, R11.1, R22.1, R23.1, SJ2.2, TSOC.6E (VTARG), U1.8 (VCC), U2.4 (VCC), U2.6 (VCC), U2.18 (AVCC)
VIN: Q1.2 (S), Q1.6 (D), U4.1 (IN)
XIN: U2.7 (PB6(XTAL1/TOSC1)), X1.3
XOUT: U2.8 (PB7(XTAL2/TOSC2)), X1.1

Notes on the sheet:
SPI1_SCK
SPI1_MISO
SPI1_MOSI
!SPI1_CS
5 V DC Max. Input
OverCurrent OverVoltage UnderVoltage Protection
3.3V LDO/Regulator
RS-485 Transceiver
EXT 5V
GND
RS-485-A
RS-485-B
ThingSoC Base (or Expansion) Board Selection
thingSoC Reference Design Open Source Sockets for IoT

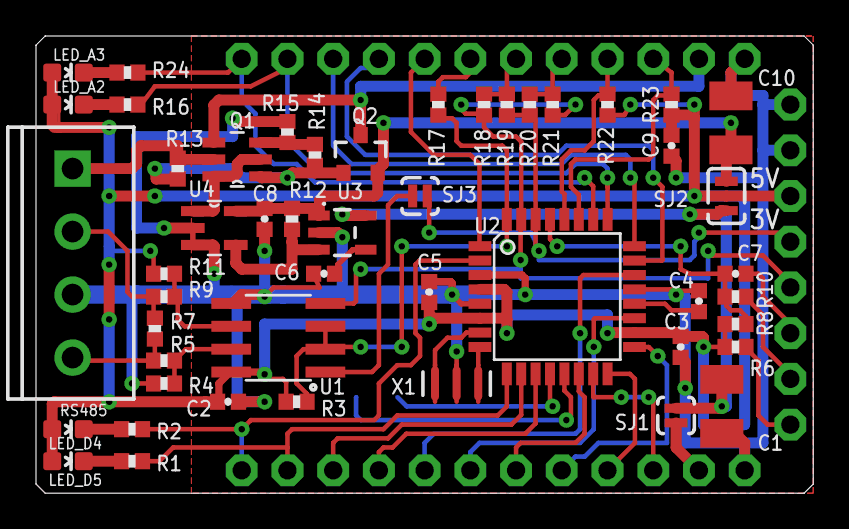
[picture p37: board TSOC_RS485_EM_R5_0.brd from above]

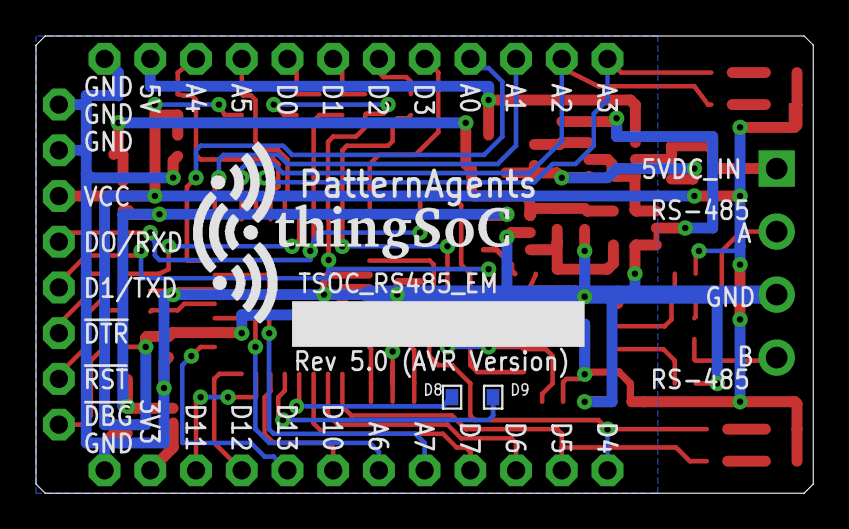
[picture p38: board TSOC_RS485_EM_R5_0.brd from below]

Board: 2 copper layers, 43.2 x 25.4 mm, 54 parts (3 on the bottom side), 53 nets.

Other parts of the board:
U$100: TSOC-LOGO-LRG

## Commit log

2016-02-19 project update
    [TSOC_RS485_EM.brd, TSOC_RS485_EM.sch, TSOC_RS485_EM.skp]
2016-03-06 update user docs
    [TSOC_RS485_EM.brd, TSOC_RS485_EM.sch]
2016-03-15 update to revision 5.0
    [TSOC_RS485_EM_R4_0.brd, TSOC_RS485_EM_R4_0.sch, TSOC_RS485_EM_R5_0.brd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]
2016-03-22 update BOM
2016-04-05 update to Rev6.0
    [TSOC_RS485_EM_R6_0.brd, TSOC_RS485_EM_R6_0.sch]
2016-07-07 update to V7_0
    [TSOC_RS485_EM.brd, TSOC_RS485_EM.sch, TSOC_RS485_EM.skp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]
2016-08-08 add product images
    [TSOC_RS485_EM.brd, TSOC_RS485_EM.sch]

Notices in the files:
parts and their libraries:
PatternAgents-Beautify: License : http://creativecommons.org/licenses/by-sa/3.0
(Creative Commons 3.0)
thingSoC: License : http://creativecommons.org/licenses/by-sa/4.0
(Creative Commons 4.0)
